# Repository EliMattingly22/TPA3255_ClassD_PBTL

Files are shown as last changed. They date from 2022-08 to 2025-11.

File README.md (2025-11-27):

# TPA3255_ClassD_PBTL
A KiCAD project for the TPA3255 amplifier in PBTL mode

This repository contains schematics, PCB layout and documentation for a compact, rack mountable PBTL (Parallel Bridged) Class‑D amplifier based on the Texas Instruments TPA3255. The design is intended to house three amplifier modules in a single 2U rack enclosure and includes front‑panel controls such as button‑enabled DC‑coupling, balanced XLR inputs/outputs, and protection/status indicators.

## Features

- TPA3255 Class‑D amplifier modules configured in PBTL(parallel bridge-tied load) mode
- Per‑channel button to toggle DC‑coupling
- Balanced XLR inputs
- Per‑channel protection: overcurrent, overtemperature, 
- Clipping indicators
- Per‑channel status LEDs (PWR GOOD / CLIP / FAULT)
- Mechanical layout and enclosure guidance for three amplifiers in a 2U rack unit

## Key electrical parameters

- Supply voltage - 24-52V
  - Power supply current rating should be sufficient for your load. At 50V a 12A supply will be enough for any application, but less is suitable for many other applications. 
- Gain is fixed. G = 21.6(2 Ohms) to 24.4(15 Ohms)
- THD depends on amplitude/power but generally 0.1-0.5%. Better than that in some operating conditions/power levels. 
- Output noise (1-25kHz) is approximately 2 microVolts/sqrt(Hz) 
- Quiescent power draw - about 100 mA per channel
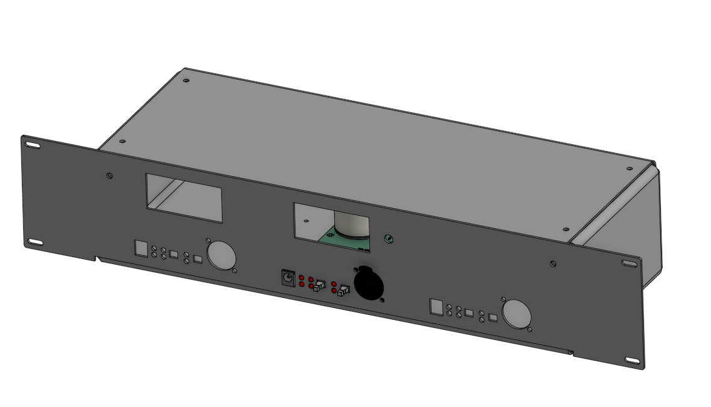
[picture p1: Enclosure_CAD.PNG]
CAD Render

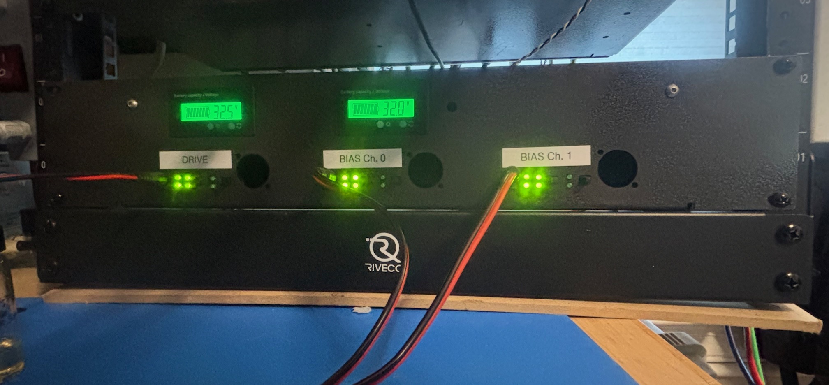
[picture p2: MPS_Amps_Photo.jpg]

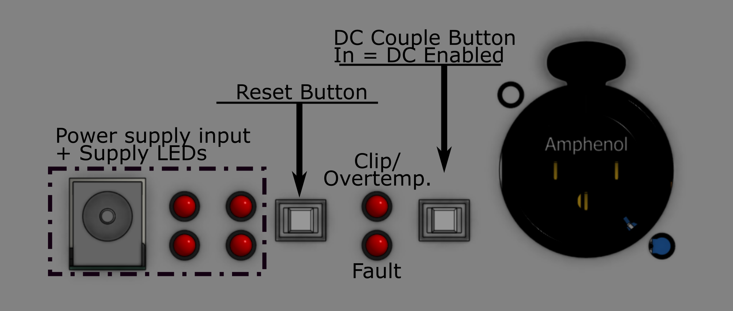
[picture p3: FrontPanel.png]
Indicators/Buttons

## Overview

This project is intended as a general-purpose amplifier capable of replacing the AE Techron 7224 in a variety of lower-power applications. It is a high‑efficiency, medium‑power (300 Watt for sure and up to 600W, in theory...) amplifier solution with balanced I/O and configurable output coupling. The DC‑coupling button lets users switch the amplifier output between AC coupling and DC coupling for use with audio systems or laboratory instruments, etc. that require true DC‑coupled operation. The enclosure is designed to hold three amplifier modules in a 19" 2U rack, with appropriate heatsinking and airflow considerations.

### In this repository:

 - The enclosure is in the top level as: "TPA3255PBTL_Enclosure.step" [Here](TPA3255PBTL_Enclosure.step)
 - There is an add-on board in the directory "Current Control Board" Which allows the user to configure it as a current-mode amplifier with an external current sensor (ACS711)

## Important Design Notes

- Balanced XLR pinout: Pin 1 = GND, Pin 2 = Hot (+), Pin 3 = Cold (−).

- If you enable DC‑coupling, verify output DC offset is within safe limits for connected device. For a transformer, this may be problematic. 

- XLR output: It is not a high-power connector so if the application requires high-current, it would be a good idea to solder directly to the PCB and/or rework the board for a different connector.

## Possible configurations
I designed it for two distinct applications, stepping-DC waveforms (i.e. staircase like waves), and pure sine waves. As the requirements are quite different between the two, there is two output filter configurations. For the DC staircases, the filter uses ferrite cores. For the sine waves, the output filter uses air-core inductors to minimize the risk of adding distortions. 

## Mechanical & Enclosure Guidance (3 amps in 2U rack)

- Standard 19" width, 2U height (88.9 mm). 
- Depth = 145 mm not including XLR connectors, which should have about 100 mm of space for the cable/bend
- XLR inputs on front and rear panel
- Speaker outputs on rear

## BOM notes

- Heatsink hardware = Advanced Thermal Solutions Inc. ATS-TI1OP-519-C1-R3
- Inductor core (for DC version) = Magnetics, a division of Spang & Co., 0079894A7HT19
  - Coated Kool Mu MAX Ferrite Core Toroid Type Length Width 1.060" (26.92mm) Diameter 0.708" (17.99mm) Height
  - Wind with three parallel strands of 18AWG magnet wire, 11 turns 

## Filter inductors

### High power (Lower linearity)
Using ferrite cores improves the efficiency (less copper losses) at the expense of some harmonic distortion. The first-stage core, L2 and L3, must carry the ripple current from the switching. The switching frequency is about 500 kHz (2 uSec period), so if it is switching 50 V every 1 uSec, at periodic steady state when the average voltage across the inductor is 0 V and so each half-period has 25 V across the inductor, the ripple current will be 2.5 A (di/dt = V/L = 25 / 10 uH = 2.5 A/uSec). The original inductor Bourns Inc. 2101-V-RC did not tolerate this well and increased the quiescent current to about 200 mA per channel and induced considerable losses into the system at higher currents. To reduce the inductor losses, this was replaced with the 0079894A7HT19 with 11 turns of three strands of 18AWG magnet wire. This core was chosen for the high saturation magnetization and fairly low losses. The datasheet specifies that the 20% reduction in inductance will occur with 320 Amp-turns so just about 30 Amps, which is more than the amplifier can output anyway. 

### High linearity
Ferrite inductors are inherently nonlinear, so for the applications that require high purity waveforms, an air core inductor was wound and only a single stage of output filtering. The inductor former (rectangular cylinder) is 22mm tall, 35mm OD, 12mm ID, and has 38 turns of 18 AWG magnet wire (about 3.3 m of wire with some extra to be cut off). The inductance was 10 uH and 200 mOhms at 50kHz. Litz wire would reduce the losses somewhat, but I wanted to avoid using Litz for this project. 

## Filter capacitors

The original capacitors (B32529D1105J289) are fine for low-frequency applications, but for >10 kHz, they should be replaced with ones which can tolerate the current being driven into them by the amplifier. At 25 kHz, the reactance is only 6.4 Ohms, so at 50 V there would be nearly 10 A of current flowing into the capacitors. I suggest much larger, much lower loss polypropylene film capacitors (e.g. R76 series or similar, and at least 300VAC rating). They will either need to be bodged onto the board (like I did) or rework the PCB to accomodate it. 

# Measurements

## Output power

### 2.5 Ohm load

After about 3 minutes with a 51V supply, 6 Amps being drawn (306W), the amplifier overheated. It reset via the front-panel button after cooling off.Note: there wasnt much forced air over the fins.

### 5 Ohm load
With 47 Vpk (1 kHz) into 5 Ohm load, the system reached a steady state.
- Heat sink: 67 C
- Small output inductors: 77 C

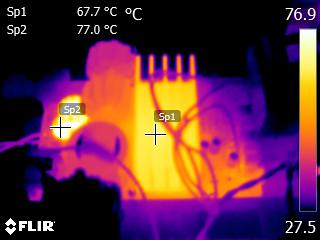
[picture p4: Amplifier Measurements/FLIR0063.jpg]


### 7.7 Ohm load
With 45.8 Vpk (1 kHz) into 7.7 Ohm load, the system reached a steady state.

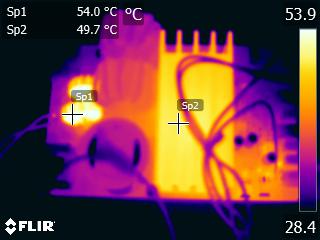
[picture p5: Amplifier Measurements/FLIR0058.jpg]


## Gain

### Air core inductor output filter
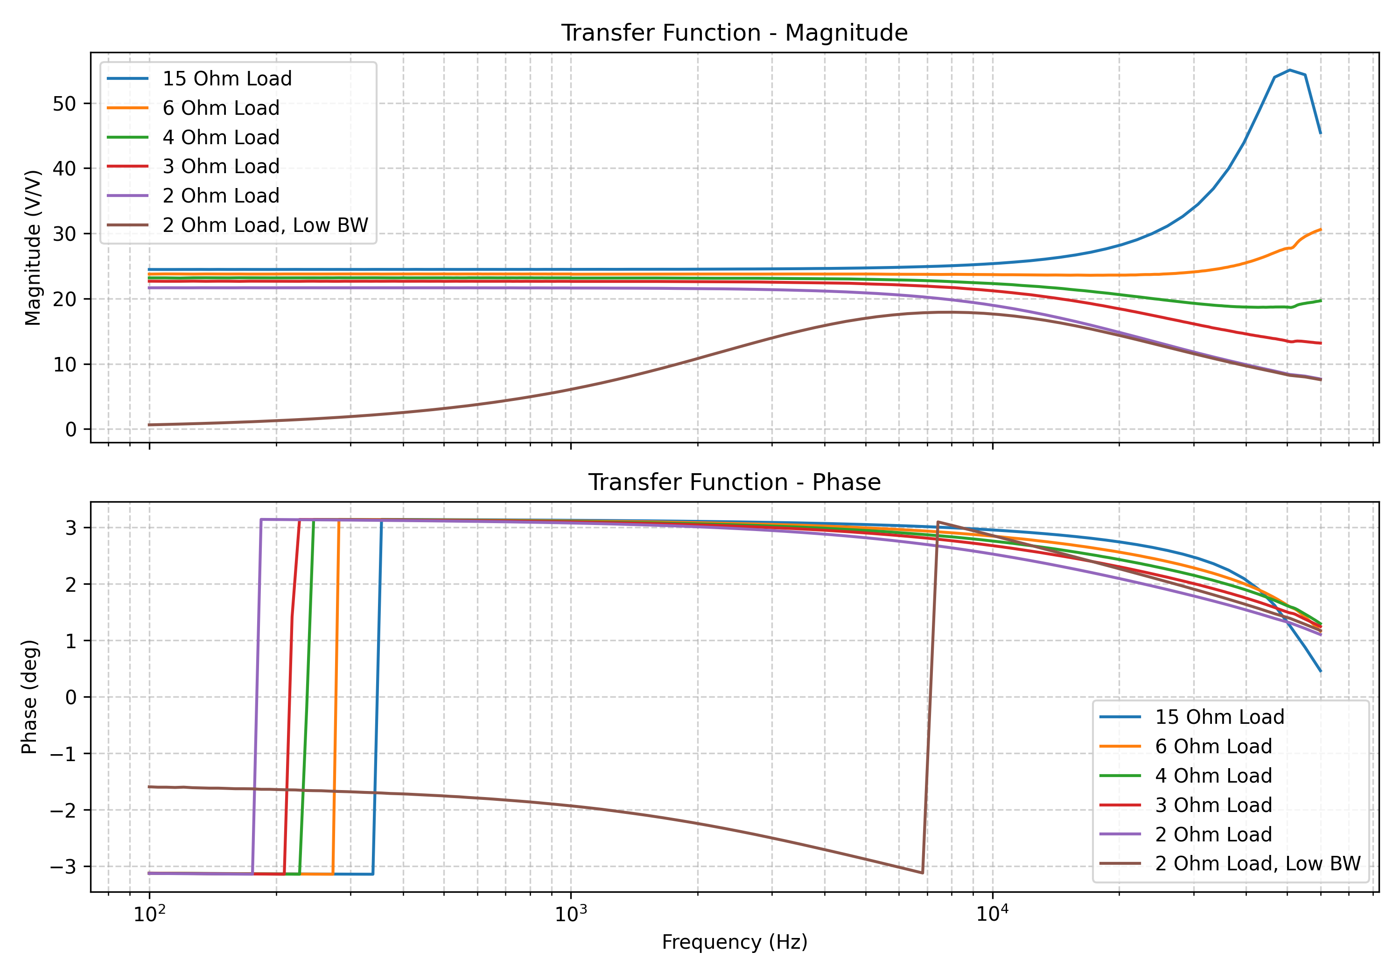
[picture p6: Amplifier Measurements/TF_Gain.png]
Transfer Function - Gain


### Ferrite core inductor output filter
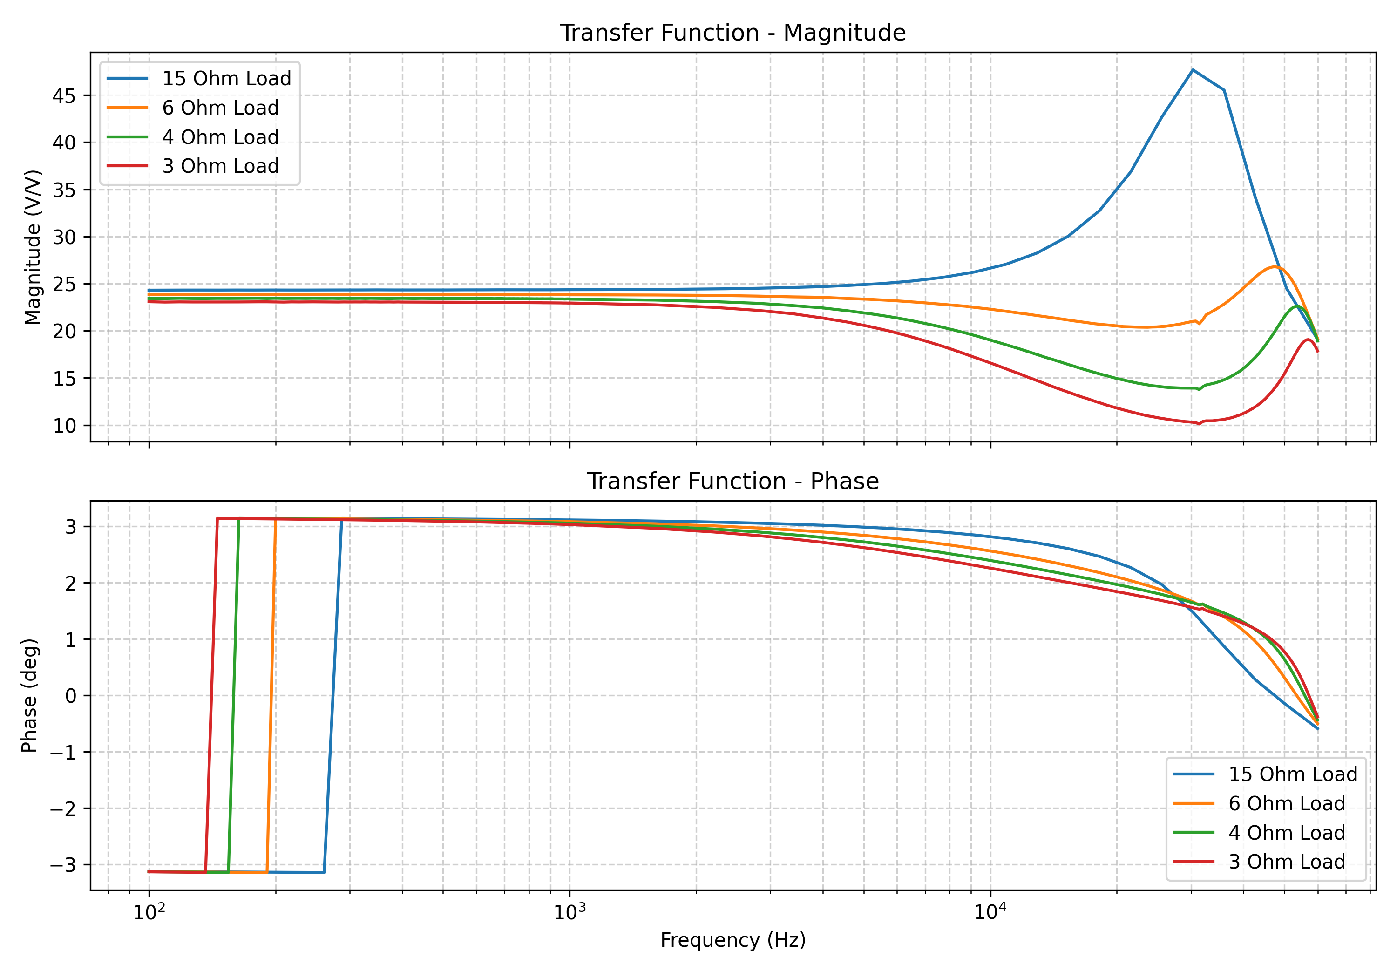
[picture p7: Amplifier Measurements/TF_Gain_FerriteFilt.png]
Transfer Function - Gain


### Low Freq characteristics, effect of jumpers on input
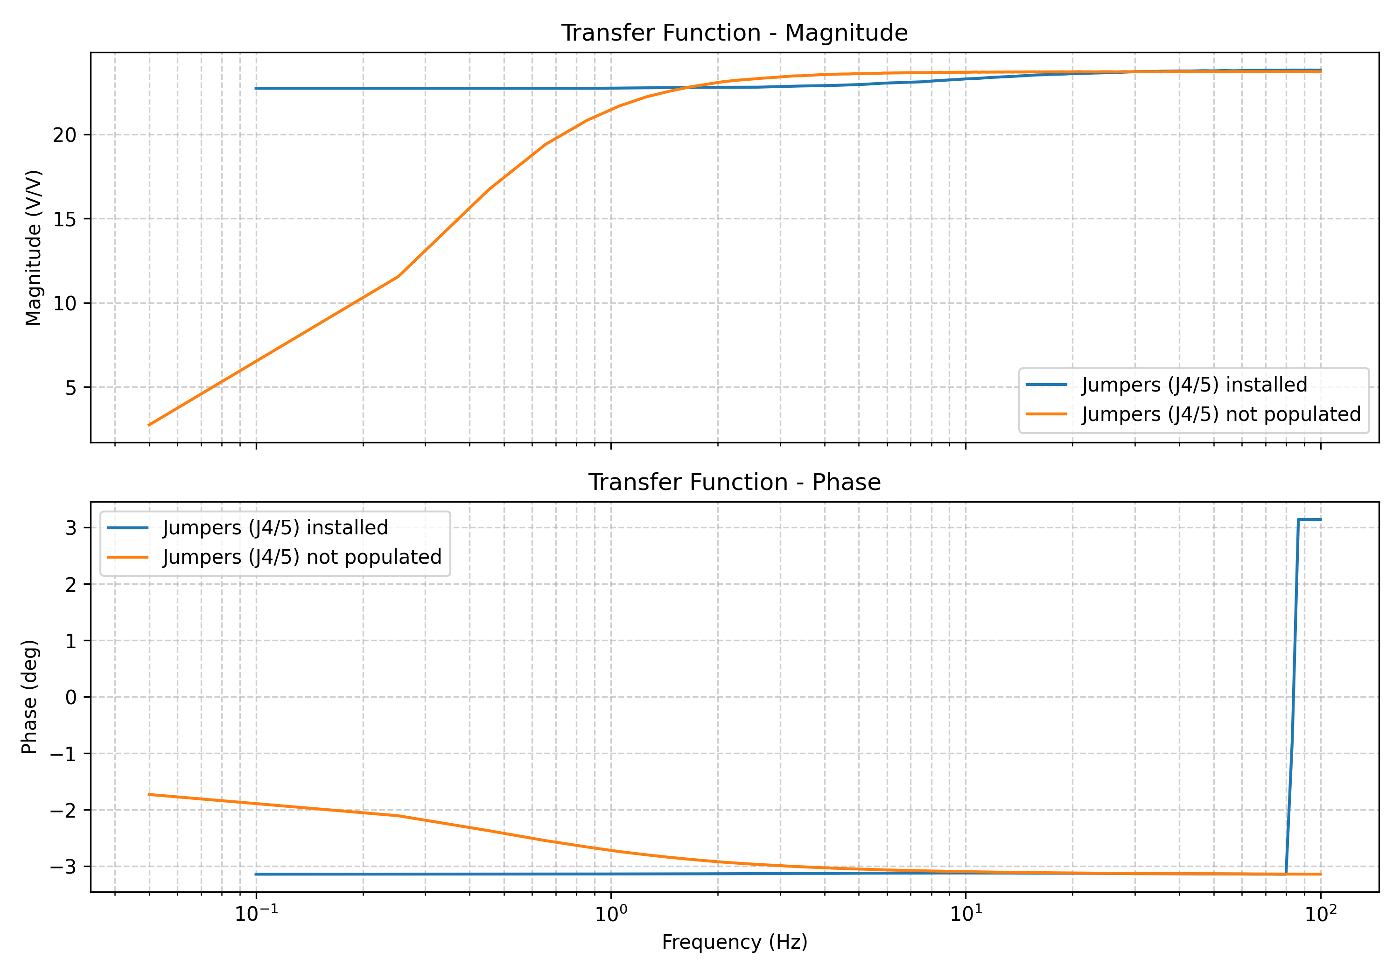
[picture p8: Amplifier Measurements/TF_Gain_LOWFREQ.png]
Transfer Function - Gain


## THD
All measurements with the wide BW/DC enabled mode. Measured the voltage across the load with a RP1025D differential probe 20x range. The probe itself has about 0.1-0.5% THD at 1kHz. 
### Ferrite output filter, 15 Ohm load:

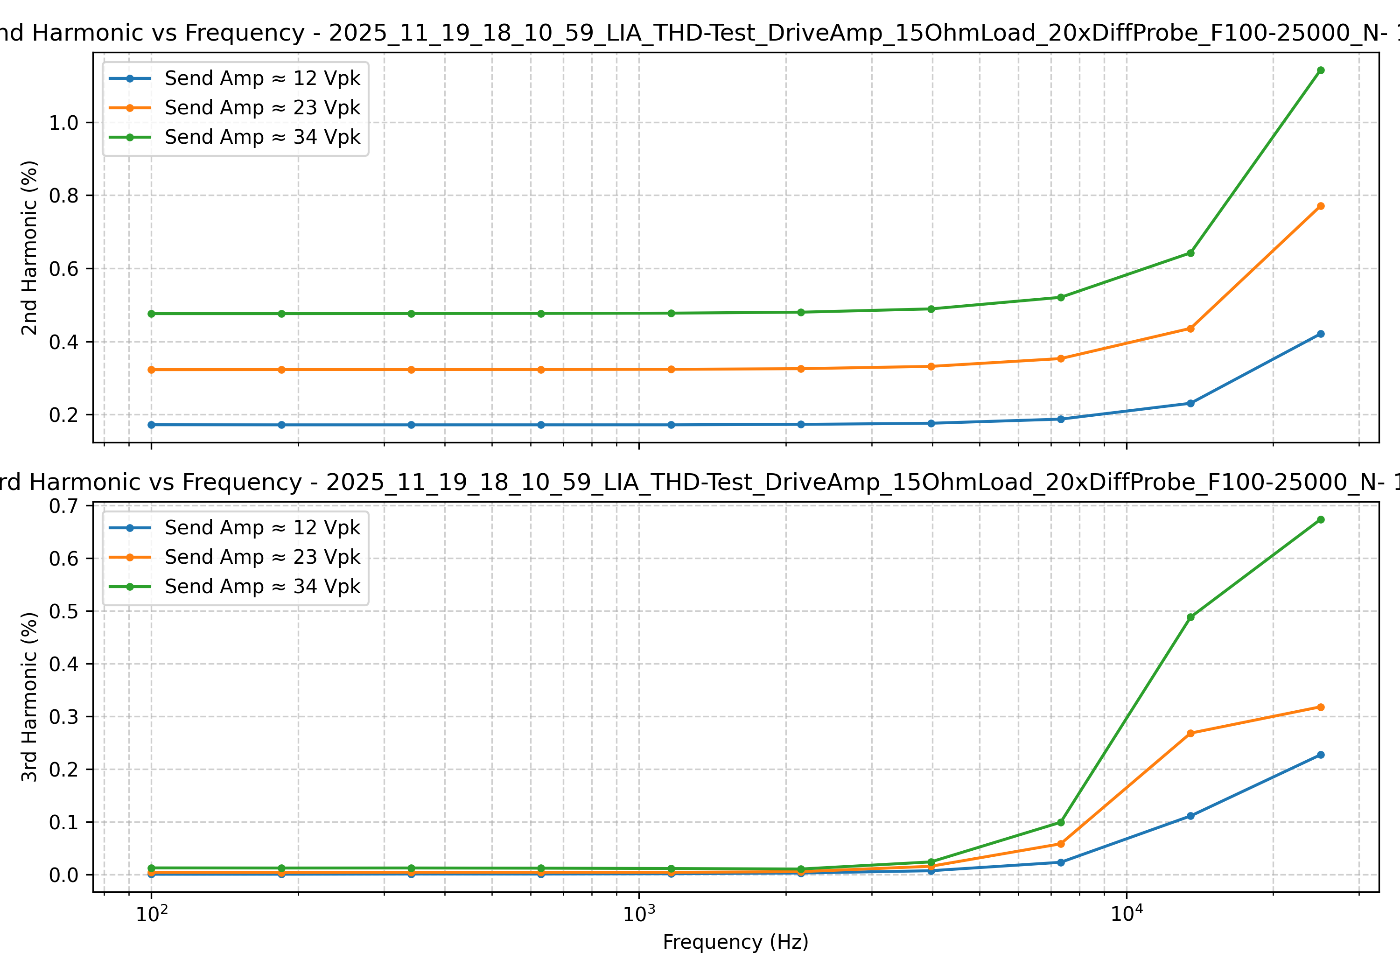
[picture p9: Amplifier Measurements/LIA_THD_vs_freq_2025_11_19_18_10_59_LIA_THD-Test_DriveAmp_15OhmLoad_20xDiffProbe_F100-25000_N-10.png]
THD 16 Ohms


### Air core inductor filter, 15 Ohm load:

THD 16 Ohms

### Air core inductor filter, 2 Ohm load:

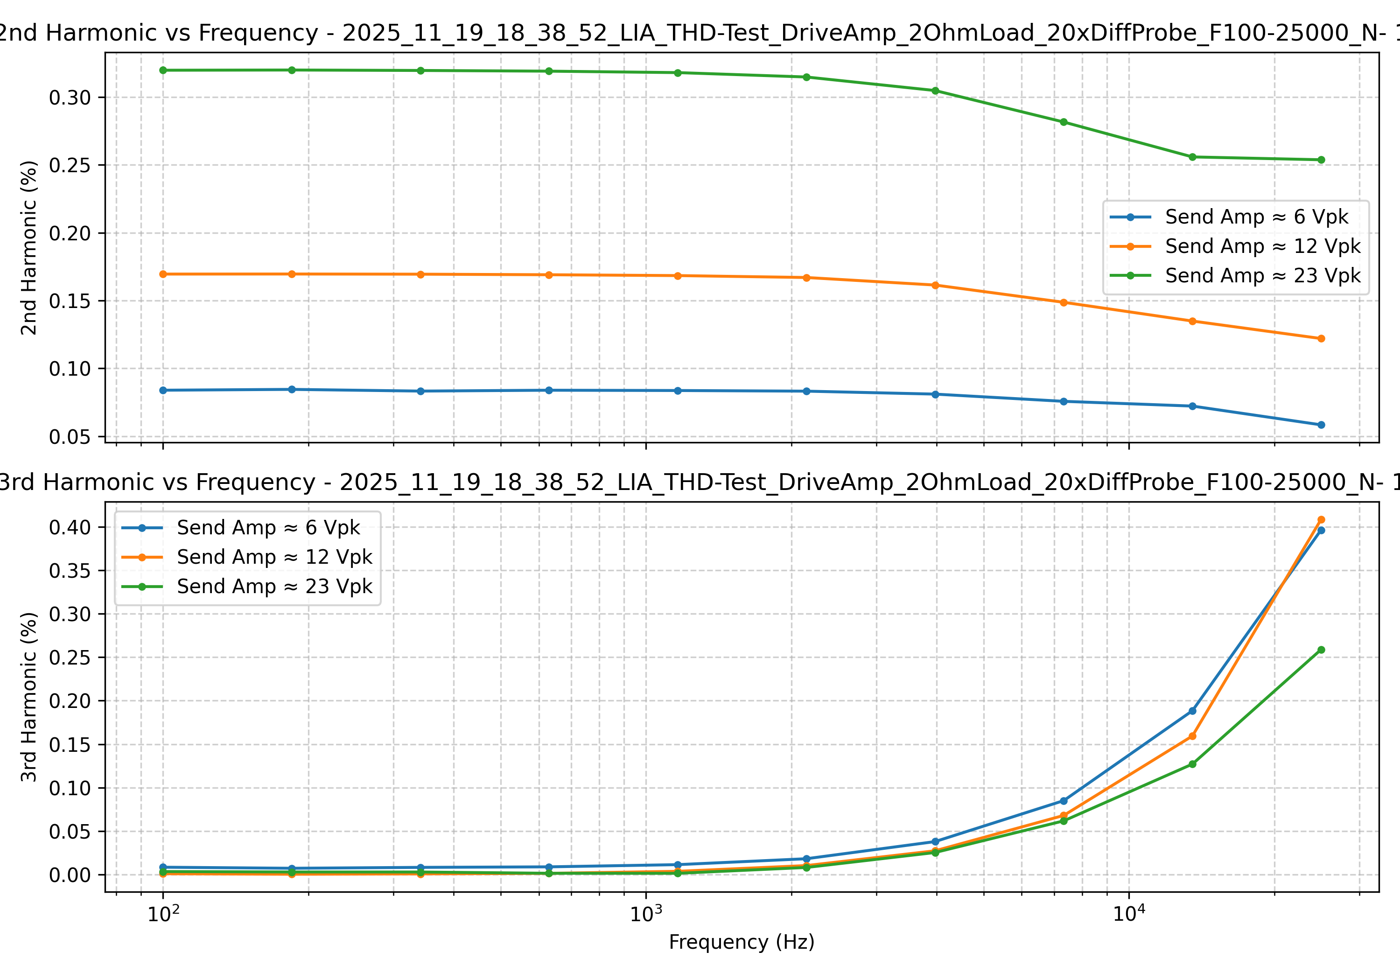
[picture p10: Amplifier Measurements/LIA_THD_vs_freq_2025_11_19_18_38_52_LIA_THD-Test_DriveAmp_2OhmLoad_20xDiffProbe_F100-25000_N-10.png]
THD 2 Ohms


## Noise, input terminated, 2 Ohm load
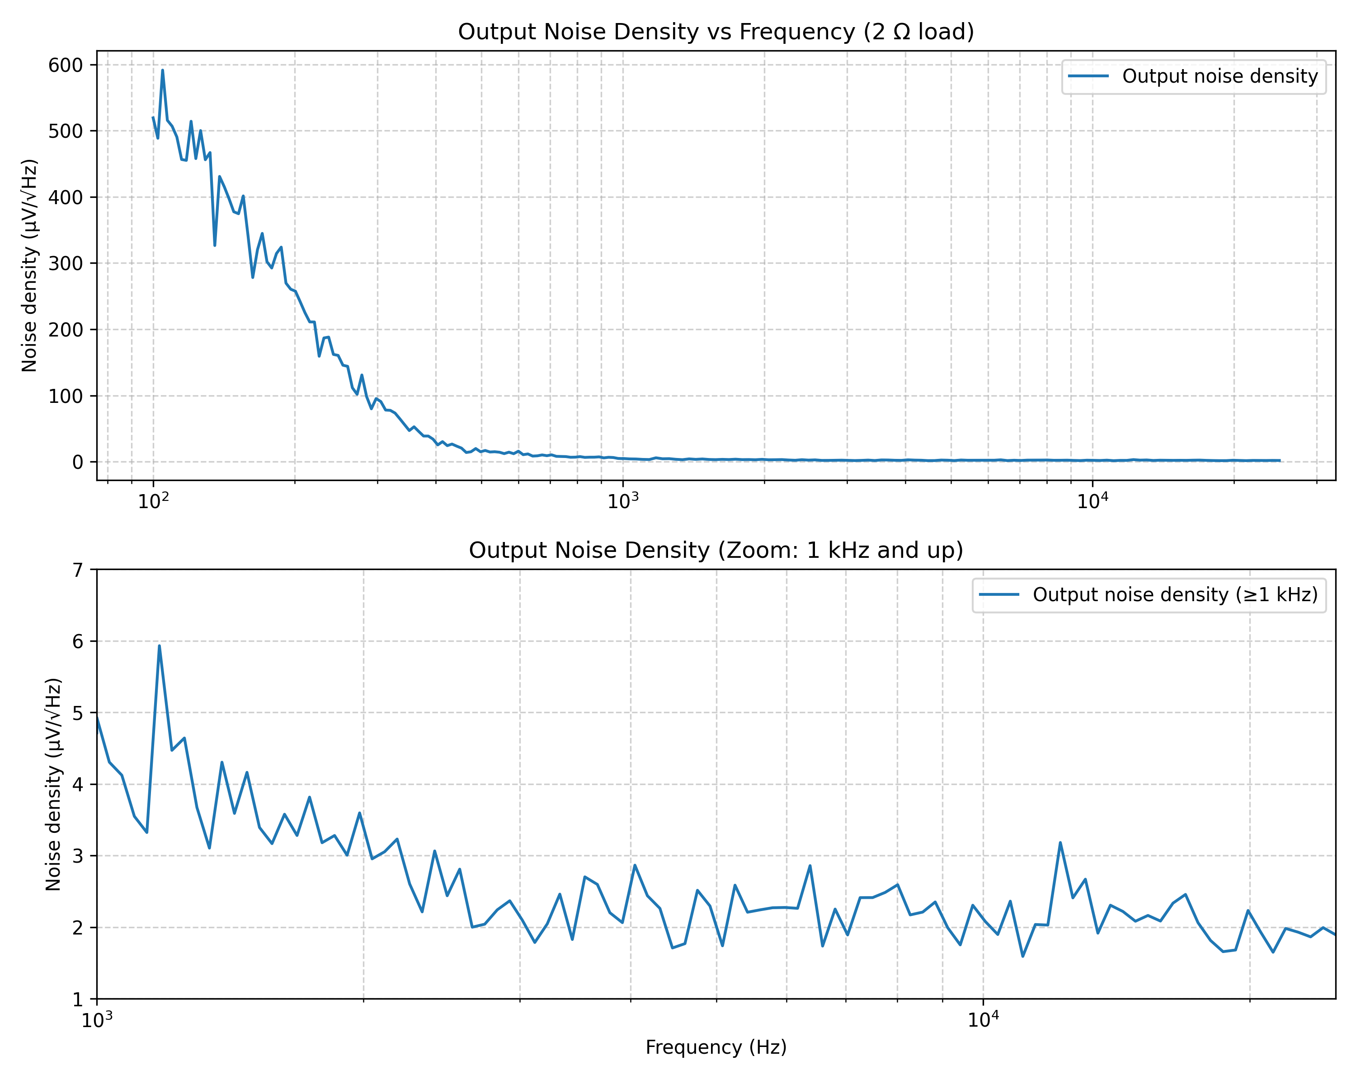
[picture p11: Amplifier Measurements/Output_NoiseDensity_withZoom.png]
Noise spectra


## Safety & Compliance Notes

- DC‑coupled outputs can damage speakers/transformers/other loads if misused 
- For commercial use verify thermal/electrical safety per applicable standards (IEC/UL) and plan for certification where required.

# Schematic details:

The output filter sheet shows the post-switching LC network and probe connectors used to tame the 500 kHz ripple. It is important to keep the filter inductor above 5 uH, per the datasheet. C18/19 present low impedance at high frequencies mitigating some RF noise when the ESL of the larger capacitors would limit their effectiveness. C20/R8 stabilize the impedance at higher frequencies. 

The Second stage filter, L4/C8/C36 and its opposite pair can be included or not depending on the application. They will be a bit lossy but add additional filtering stages to mitigate higher frequency noise. These are not populated in the air core filter version becasuse that application has another filter external to this amplifier board. 

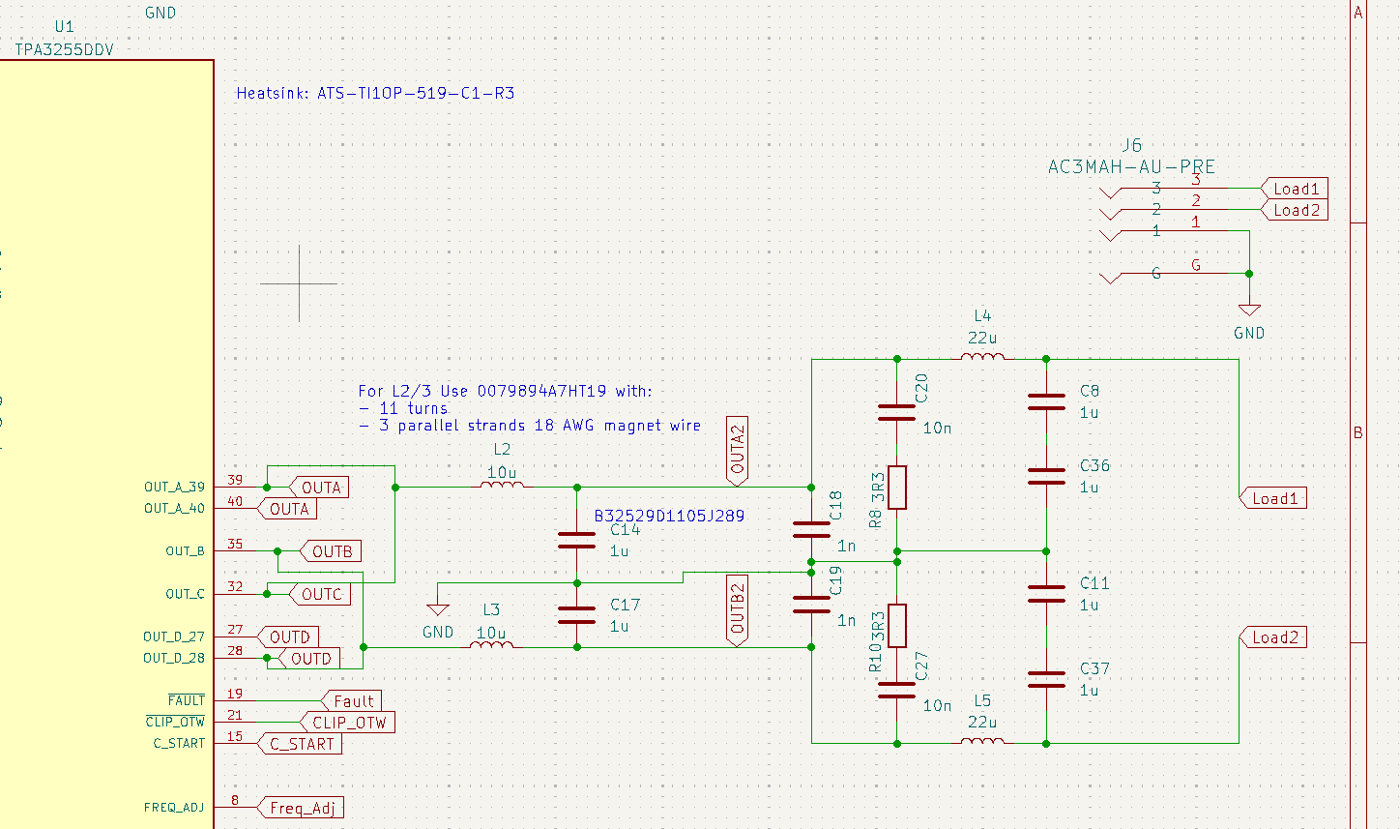
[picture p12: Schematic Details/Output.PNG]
Output Filter


The LED page documents the front-panel status indicators, including the current-limit, clip, and fault drivers tied into the protection logic. See the datasheet for details on the logic. 

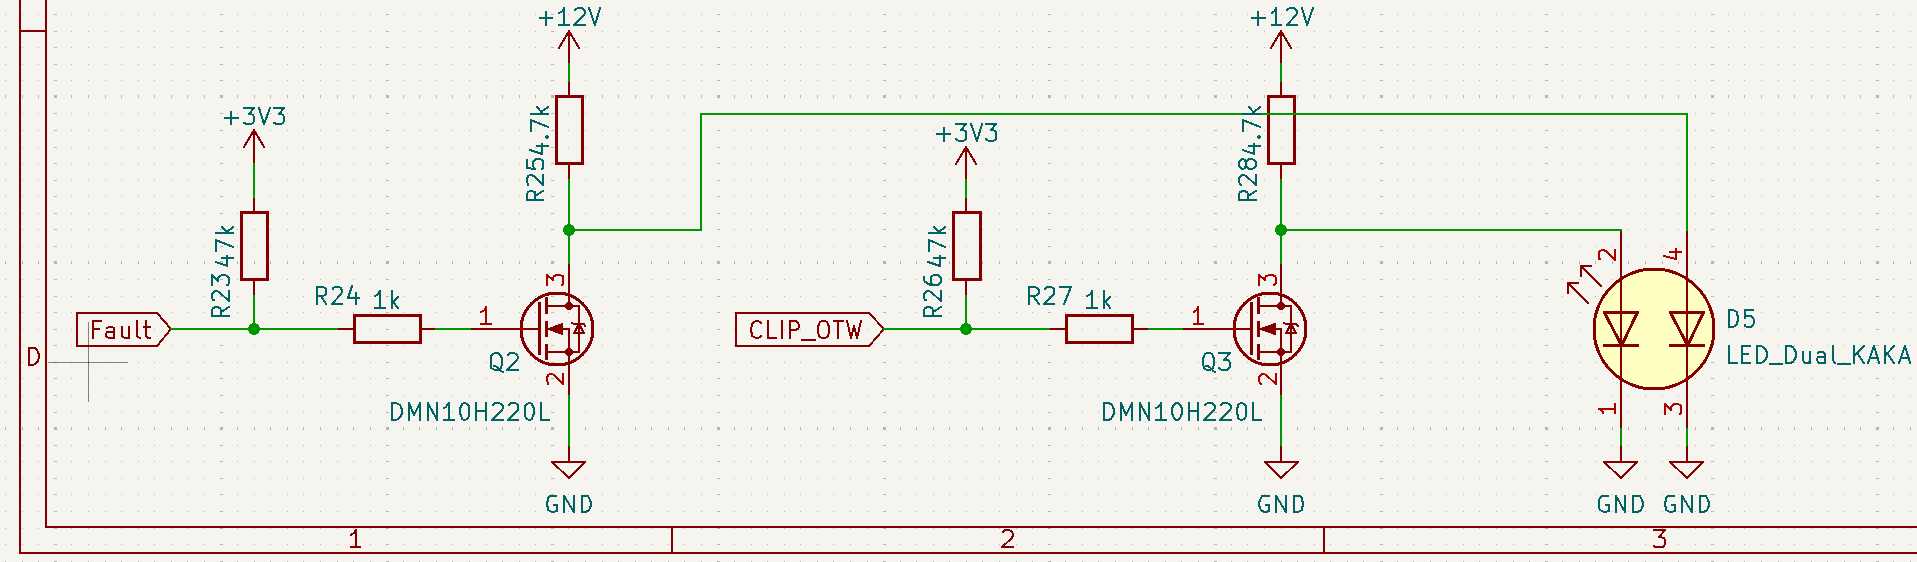
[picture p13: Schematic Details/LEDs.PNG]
LEDs


The power sheet covers the main supply routing, bulk capacitance, and bias regulation stages that feed the TPA3255 module and housekeeping rails.

Note that there is a reverse voltage protection PMOS, the Zener diode protects it from too high VGS.

There are also LEDs to indicate each of the four rails are working (well that there is power to them, they may be enabled but the rails be incorrect). 

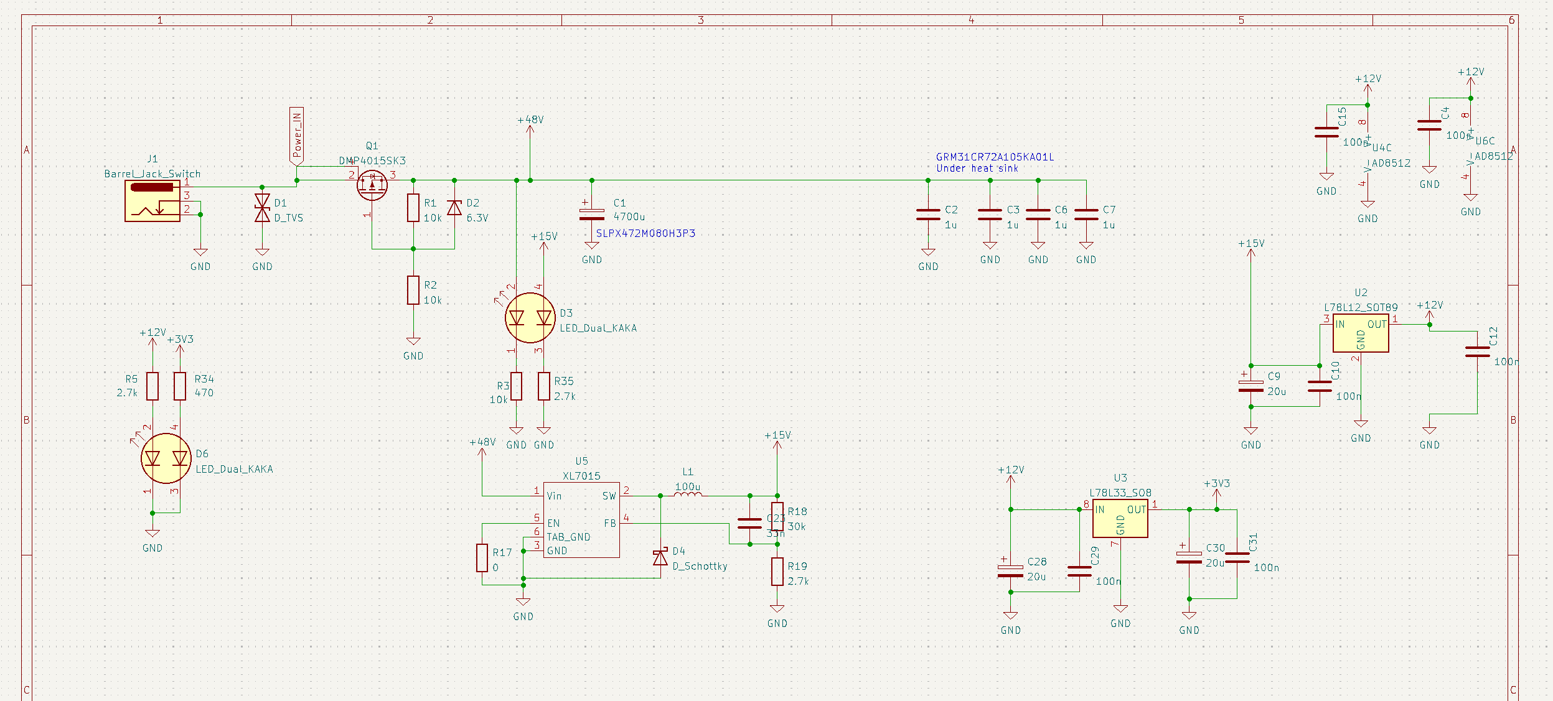
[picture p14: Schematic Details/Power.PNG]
Power


The signals schematic captures the balanced input conditioning, relay-controlled coupling paths, etc.

The signal either passes throught the AC coupling capacitors, C15/43 (the values of which should be chosen based on the application), and are bypassed in DC coupled mode by the latching switch. It then goes through a Diff->SE stage (U4A) which sets the reference point to be 3.8V. The signal then is buffered and turned into a differential signal either going through large AC coupling caps or through jumpers J4/5 which need to be shorted for true DC coupling mode. 

RV1 allows offset trimming.

U7A/B allows for external voltage monitoring, via a home-brew high signal instrumentation amplifier setup, if needed. There is only a test point, but a wire could be easily soldered and a connector added if desired. 

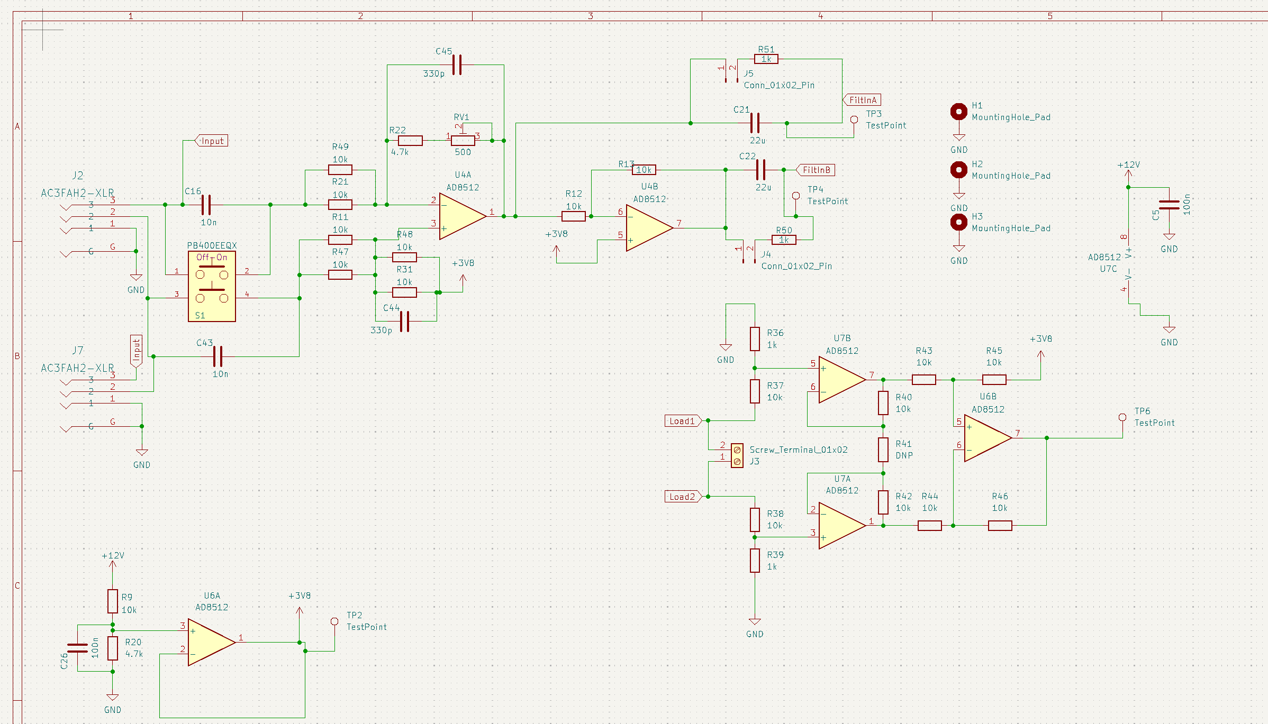
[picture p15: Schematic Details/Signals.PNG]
Signals


The startup page highlights inrush limiting, sequencing, and reset circuitry that ensures the amplifier powers up quietly without tripping protection as suggested by the datasheet. Initially the capacitor holds Q4 low, which means Q5 is enabled, pulling the RST to gnd, but when the capacitor charges, Q4 conducts pulling the gate of Q5 down and R52 pulls RST high.

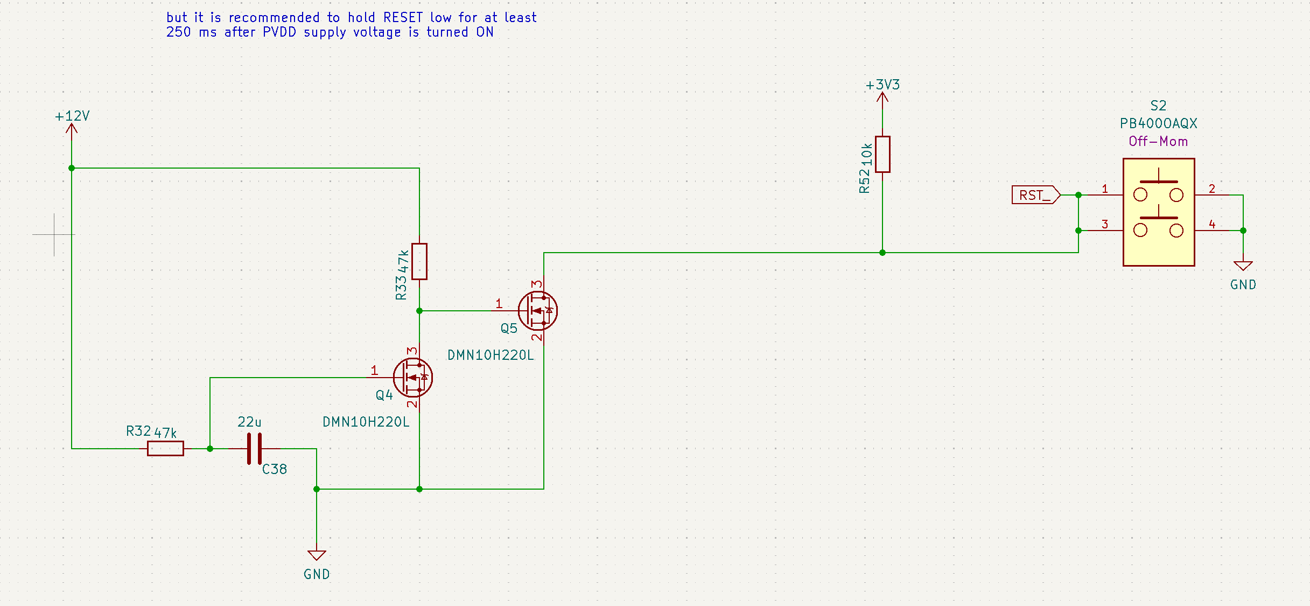
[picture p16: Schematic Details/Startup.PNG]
Startup


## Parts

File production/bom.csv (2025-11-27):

Designator | Footprint | Quantity | Value | LCSC Part #
C1 | CP_Radial_D35.0mm_P10.00mm_SnapIn | 1 | 4700u
C10, C12, C15, C24, C25, C26, C29, C31, C4, C5 | 0805 | 10 | 100n
C11, C14, C17, C36, C37, C8 | C_Rect_L7.2mm_W7.2mm_P5.00mm_FKS2_FKP2_MKS2_MKP2 | 6 | 1u
C13, C40, C41 | 0805 | 3 | 1u
C16, C20, C27, C43 | 0805 | 4 | 10n
C18, C19 | 0805 | 2 | 1n
C2, C3, C6, C7 | 1206 | 4 | 1u
C21, C22, C38 | 1206 | 3 | 47u
C23, C32, C33, C34, C35 | 0805 | 5 | 33n
C28, C30, C9 | CP_Radial_D6.3mm_P2.50mm | 3 | 20u
C42 | 0805 | 1 | 47n
C44, C45 | 0805 | 2 | 330p
D1 | D_SOD-123 | 1 | D_TVS
D2 | D_SOD-123 | 1 | 6.3V
D3, D5, D6 | IC4_WP934EB_2GD_KNB | 3 | LED_Dual_KAKA
D4 | D_SOD-123 | 1 | D_Schottky
J1 | BarrelJack_GCT_DCJ200-10-A_Horizontal | 1 | Barrel_Jack_Switch
J2, J7 | AC3FAH2-F-XLR | 2 | AC3FAH2-XLR
J3 | TerminalBlock_Phoenix_MKDS-1,5-2-5.08_1x02_P5.08mm_Horizontal | 1 | Screw_Terminal_01x02
J4, J5 | PinHeader_1x02_P1.27mm_Vertical | 2 | Conn_01x02_Pin
J6 | AC3MAH-AU-PRE_AMP | 1 | AC3MAH-AU-PRE
L1 | MWPY8040 | 1 | 100u | C501759
L2, L3 | L_Toroid_Vertical_L22.4mm_W10.2mm_P7.90mm_Vishay_TJ4 | 2 | 10u
L4, L5 | L_Toroid_Vertical_L22.4mm_W10.2mm_P7.90mm_Vishay_TJ4 | 2 | 22u
Q1 | TO-252-3_TabPin4 | 1 | DMP4015SK3
Q2, Q3, Q4, Q5 | SOT-23 | 4 | DMN10H220L
R1, R11, R12, R13, R2, R21, R3, R31, R37, R38, R40, R42, R43, R44, R45, R46, R47, R48, R49, R52, R9 | 0805 | 21 | 10k
R10, R8 | 0805 | 2 | 3R3
R14, R15, R16, R17, R4 | 0805 | 5 | 0
R18, R30 | 0805 | 2 | 30k
R19, R35, R5 | 0805 | 3 | 2.7k
R20, R22, R25, R28 | 0805 | 4 | 4.7k
R23, R26, R32, R33 | 0805 | 4 | 47k
R24, R27, R36, R39, R50, R51 | 0805 | 6 | 1k
R29 | 0805 | 1 | 22k
R34 | 0805 | 1 | 470
R6, R7 | 0805 | 2 | 3.3
RV1 | Potentiometer_Bourns_3296W_Vertical | 1 | 500
S1 | SW_PB400EEQX | 1 | PB400EEQX
S2 | SW_PB400EEQX | 1 | PB400OAQX
TP1, TP2, TP3, TP4, TP5, TP6, TP7, TP8 | TestPoint_THTPad_1.0x1.0mm_Drill0.5mm | 8 | TestPoint
U1 | SOP63P810X120-44N | 1 | TPA3255DDV
U2 | SOT-89-3 | 1 | L78L12_SOT89
U3 | SOIC-8_3.9x4.9mm_P1.27mm | 1 | L78L33_SO8
U4, U6, U7 | SO-8_3.9x4.9mm_P1.27mm | 3 | AD8512
U5 | XL7015E1 | 1 | XL7015

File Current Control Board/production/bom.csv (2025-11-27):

Designator | Footprint | Quantity | Value | LCSC Part #
C1 | 0805 | 1 | 47n
C10, C11, C12, C13, C14, C15, C16, C17 | 0805 | 8 | 100n
C2 | 0805 | 1 | 22n
C3 | 0805 | 1 | 10n
C4 | 0805 | 1 | 470p
C5 | 0805 | 1 | 1n
C6, C9 | 0805 | 2 | 10u
C7, C8 | CP_Radial_D6.3mm_P2.50mm | 2 | 100u
D1, D2 | D_SOD-123 | 2 | 2.5
D3, D4 | 0805 | 2 | LED
J1 | AC3FAH2-F-XLR | 1 | AC3FAH2-XLR
J2 | AC3MAH-AU-PRE_AMP | 1 | AC3MAH-AU-PRE
J3, J4, J5 | Banana-FCR7350L | 3 | Banana
J7 | 31-5486-1010 BNC Panel RA | 1 | Conn_Coaxial
R1, R12, R13, R14, R15, R17, R2, R3, R4, R6, R7, R8, R9 | 0805 | 13 | 1k
R10, R11, R18, R19, R20, R5 | 0805 | 6 | 10k
R16 | 0805 | 1 | 220
RV1 | Potentiometer_Bourns_3296W_Vertical | 1 | 10k
SW1 | SW_DIP_SPSTx04_Slide_9.78x12.34mm_W8.61mm_P2.54mm | 1 | SW_DIP_x04
TP1, TP2, TP3, TP4, TP5 | TestPoint_Loop_D2.50mm_Drill1.0mm | 5 | 5002
U1, U2, U3, U4 | SOIC-8_3.9x4.9mm_P1.27mm | 4 | ADA4610-2xR
U5 | SOIC-8_3.9x4.9mm_P1.27mm | 1 | L78L05_SO8

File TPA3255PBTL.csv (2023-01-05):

Source: | C:\Users\elima\OneDrive\Documents\GitHub\TPA3255_ClassD_PBTL\TPA3255PBTL.kicad_sch
Date: | 12/17/2022 9:43:32 PM
Tool: | Eeschema (6.0.0)
Generator: | C:\Program Files\KiCad\6.0\bin\scripting\plugins/bom_csv_grouped_by_value.py
Component Count: | 91
Individual Components:
Item | Qty | Reference(s) | Value | LibPart | Footprint | Datasheet | LCSC | MANUFACTURER | MAXIMUM_PACKAGE_HEIGHT | PARTREV | STANDARD
 |  | C1 | C_Polarized | Device:C_Polarized | Capacitor_THT:CP_Radial_D12.5mm_P5.00mm | ~
 |  | C2 | C_Polarized | Device:C_Polarized | Capacitor_THT:CP_Radial_D12.5mm_P5.00mm | ~
 |  | C3 | C | Device:C | Capacitor_SMD:C_1206_3216Metric | ~
 |  | C4 | C_Polarized | Device:C_Polarized | Capacitor_THT:CP_Radial_D12.5mm_P5.00mm | ~
 |  | C5 | C_Polarized | Device:C_Polarized | Capacitor_THT:CP_Radial_D12.5mm_P5.00mm | ~
 |  | C6 | C | Device:C | Capacitor_SMD:C_1206_3216Metric | ~
 |  | C7 | C | Device:C | Capacitor_SMD:C_1206_3216Metric | ~
 |  | C8 | C | Device:C | Capacitor_SMD:C_1206_3216Metric | ~
 |  | C9 | 20u | Device:C_Polarized | Capacitor_THT:CP_Radial_D5.0mm_P2.50mm | ~
 |  | C10 | 100n | Device:C | Capacitor_SMD:C_0805_2012Metric | ~
 |  | C11 | 20u | Device:C_Polarized | Capacitor_THT:CP_Radial_D5.0mm_P2.50mm | ~
 |  | C12 | 100n | Device:C | Capacitor_SMD:C_0805_2012Metric | ~
 |  | C13 | 1u | Device:C | Capacitor_SMD:C_0805_2012Metric | ~
 |  | C15 | 100n | Device:C | Capacitor_SMD:C_0805_2012Metric | ~
 |  | C16 | 100n | Device:C | Capacitor_SMD:C_0805_2012Metric | ~
 |  | C17 | 10n | Device:C | Capacitor_SMD:C_0805_2012Metric | ~
 |  | C18 | 1n | Device:C | Capacitor_SMD:C_0805_2012Metric | ~
 |  | C19 | 100p | Device:C | Capacitor_SMD:C_0805_2012Metric | ~
 |  | C20 | 100n | Device:C | Capacitor_SMD:C_0805_2012Metric | ~
 |  | C21 | 1u | Device:C | Capacitor_SMD:C_0805_2012Metric | ~
 |  | C22 | 1u | Device:C | Capacitor_SMD:C_0805_2012Metric | ~
 |  | C23 | 33n | Device:C | Capacitor_SMD:C_0805_2012Metric | ~
 |  | C24 | 100n | Device:C | Capacitor_SMD:C_0805_2012Metric | ~
 |  | C25 | 100n | Device:C | Capacitor_SMD:C_0805_2012Metric | ~
 |  | C26 | 100n | Device:C | Capacitor_SMD:C_0805_2012Metric | ~
 |  | C27 | 100n | Device:C | Capacitor_SMD:C_0805_2012Metric | ~
 |  | C28 | 20u | Device:C_Polarized | Capacitor_THT:CP_Radial_D5.0mm_P2.50mm | ~
 |  | C29 | 100n | Device:C | Capacitor_SMD:C_0805_2012Metric | ~
 |  | C30 | 20u | Device:C_Polarized | Capacitor_THT:CP_Radial_D5.0mm_P2.50mm | ~
 |  | C31 | 100n | Device:C | Capacitor_SMD:C_0805_2012Metric | ~
 |  | C32 | 33n | Device:C | Capacitor_SMD:C_0805_2012Metric | ~
 |  | C33 | 33n | Device:C | Capacitor_SMD:C_0805_2012Metric | ~
 |  | C34 | 33n | Device:C | Capacitor_SMD:C_0805_2012Metric | ~
 |  | C35 | 33n | Device:C | Capacitor_SMD:C_0805_2012Metric | ~
 |  | C38 | 4.7n | Device:C | Capacitor_THT:C_Rect_L18.0mm_W6.0mm_P15.00mm_FKS3_FKP3 | ~
 |  | C39 | 4.7n | Device:C | Capacitor_THT:C_Rect_L18.0mm_W6.0mm_P15.00mm_FKS3_FKP3 | ~
 |  | C40 | 1u | Device:C | Capacitor_SMD:C_0805_2012Metric | ~
 |  | C41 | 1u | Device:C | Capacitor_SMD:C_0805_2012Metric | ~
 |  | C42 | 100n | Device:C | Capacitor_SMD:C_0805_2012Metric | ~
 |  | D1 | D_TVS | Device:D_TVS | Diode_SMD:D_SOD-123 | ~
 |  | D2 | 6.3V | Device:D_Zener | Diode_SMD:D_SOD-123 | ~
 |  | D3 | LED | Device:LED | LED_THT:LED_D3.0mm_Horizontal_O1.27mm_Z2.0mm | ~
 |  | D4 | D_Schottky | Device:D_Schottky | Diode_SMD:D_SOD-123 | ~
 |  | D5 | LED | Device:LED | LED_THT:LED_D3.0mm_Horizontal_O1.27mm_Z2.0mm | ~
 |  | D6 | LED | Device:LED | LED_THT:LED_D3.0mm_Horizontal_O1.27mm_Z2.0mm | ~
 |  | D7 | LED | Device:LED | LED_THT:LED_D3.0mm_Horizontal_O1.27mm_Z2.0mm | ~
 |  | J1 | Barrel_Jack_Switch | Connector:Barrel_Jack_Switch | Connector_BarrelJack:BarrelJack_GCT_DCJ200-10-A_Horizontal | ~
 |  | J2 | Conn_Coaxial | Connector:Conn_Coaxial | Connector_Coaxial:BNC_TEConnectivity_1478035_Horizontal | ~
 |  | J3 | Conn_02x04_Odd_Even | Connector_Generic:Conn_02x04_Odd_Even | Connector_PinHeader_2.54mm:PinHeader_2x04_P2.54mm_Vertical | ~
 |  | L1 | 100u | Device:L | Eli_Lib:MWPY8040 | ~ | C501759
 |  | L2 | 10u | Device:L | Inductor_THT:L_Toroid_Vertical_L22.4mm_W10.2mm_P7.90mm_Vishay_TJ4 | ~
 |  | L3 | 10u | Device:L | Inductor_THT:L_Toroid_Vertical_L22.4mm_W10.2mm_P7.90mm_Vishay_TJ4 | ~
 |  | Q1 | DMP4015SK3 | Eli:DMP4015SK3 | Package_TO_SOT_SMD:TO-252-3_TabPin4 | ~
 |  | Q2 | DMN10H220L | Transistor_FET:DMN10H220L | Package_TO_SOT_SMD:SOT-23 | http://www.diodes.com/assets/Datasheets/DMN10H220L.pdf
 |  | Q3 | DMN10H220L | Transistor_FET:DMN10H220L | Package_TO_SOT_SMD:SOT-23 | http://www.diodes.com/assets/Datasheets/DMN10H220L.pdf
 |  | R1 | 10k | Device:R | Resistor_SMD:R_0805_2012Metric | ~
 |  | R2 | 10k | Device:R | Resistor_SMD:R_0805_2012Metric | ~
 |  | R3 | 10k | Device:R | Resistor_SMD:R_0805_2012Metric | ~
 |  | R4 | 0 | Device:R | Resistor_SMD:R_0805_2012Metric | ~
 |  | R5 | 1k | Device:R | Resistor_SMD:R_0805_2012Metric | ~
 |  | R6 | 3.3 | Device:R | Resistor_SMD:R_0805_2012Metric | ~
 |  | R7 | 3.3 | Device:R | Resistor_SMD:R_0805_2012Metric | ~
 |  | R8 | 10k | Device:R | Resistor_SMD:R_0805_2012Metric | ~
 |  | R9 | 10k | Device:R | Resistor_SMD:R_0805_2012Metric | ~
 |  | R10 | 10k | Device:R | Resistor_SMD:R_0805_2012Metric | ~
 |  | R11 | 10k | Device:R | Resistor_SMD:R_0805_2012Metric | ~
 |  | R12 | 10k | Device:R | Resistor_SMD:R_0805_2012Metric | ~
 |  | R13 | 10k | Device:R | Resistor_SMD:R_0805_2012Metric | ~
 |  | R14 | 0 | Device:R | Resistor_SMD:R_0805_2012Metric | ~
 |  | R15 | 0 | Device:R | Resistor_SMD:R_0805_2012Metric | ~
 |  | R16 | 0 | Device:R | Resistor_SMD:R_0805_2012Metric | ~
 |  | R17 | 0 | Device:R | Resistor_SMD:R_0805_2012Metric | ~
 |  | R18 | 30k | Device:R | Resistor_SMD:R_0805_2012Metric | ~
 |  | R19 | 2.7k | Device:R | Resistor_SMD:R_0805_2012Metric | ~
 |  | R20 | 10k | Device:R | Resistor_SMD:R_0805_2012Metric | ~
 |  | R21 | 10k | Device:R | Resistor_SMD:R_0805_2012Metric | ~
 |  | R22 | 10k | Device:R | Resistor_SMD:R_0805_2012Metric | ~
 |  | R23 | 47k | Device:R | Resistor_SMD:R_0805_2012Metric | ~
 |  | R24 | 1k | Device:R | Resistor_SMD:R_0805_2012Metric | ~
 |  | R25 | 4.7k | Device:R | Resistor_SMD:R_0805_2012Metric | ~
 |  | R26 | 47k | Device:R | Resistor_SMD:R_0805_2012Metric | ~
 |  | R27 | 1k | Device:R | Resistor_SMD:R_0805_2012Metric | ~
 |  | R28 | 4.7k | Device:R | Resistor_SMD:R_0805_2012Metric | ~
 |  | R29 | 22k | Device:R | Resistor_SMD:R_0805_2012Metric | ~
 |  | R30 | 30k | Device:R | Resistor_SMD:R_0805_2012Metric | ~
 |  | SW1 | SW_Push_Dual | Switch:SW_Push_Dual | Button_Switch_SMD:SW_SPST_Omron_B3FS-105xP | ~
 |  | U1 | TPA3255DDV | Eli_v6Lib:TPA3255DDV | Eli_Lib:SOP63P810X120-44N |  |  | Texas Instruments | 1.2 mm | A | IPC-7351B
 |  | U2 | L78L12_SOT89 | Regulator_Linear:L78L12_SOT89 | Package_TO_SOT_SMD:SOT-89-3 | http://www.st.com/content/ccc/resource/technical/document/datasheet/15/55/e5/aa/23/5b/43/fd/CD00000446.pdf/files/CD00000446.pdf/jcr:content/translations/en.CD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
 |  | U3 | L78L33_SO8 | Regulator_Linear:L78L33_SO8 | Package_SO:SOIC-8_3.9x4.9mm_P1.27mm | http://www.st.com/content/ccc/resource/technical/document/datasheet/15/55/e5/aa/23/5b/43/fd/CD00000446.pdf/files/CD00000446.pdf/jcr:content/translations/en.CD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
 |  | U4 | NE5532 | Amplifier_Operational:NE5532 | Package_SO:SO-8_3.9x4.9mm_P1.27mm | http://www.ti.com/lit/ds/symlink/ne5532.pdf
 |  | U5 | XL7015 | Eli_v6Lib:XL7015 | Package_TO_SOT_SMD:TO-252-5_TabPin6
Collated Components:
Item | Qty | Reference(s) | Value | LibPart | Footprint | Datasheet | LCSC | MANUFACTURER | MAXIMUM_PACKAGE_HEIGHT | PARTREV | STANDARD
1 | 4 | C1, C2, C4, C5 | C_Polarized | Device:C_Polarized | Capacitor_THT:CP_Radial_D12.5mm_P5.00mm | ~
2 | 4 | C3, C6, C7, C8 | C | Device:C | Capacitor_SMD:C_1206_3216Metric | ~
3 | 4 | C9, C11, C28, C30 | 20u | Device:C_Polarized | Capacitor_THT:CP_Radial_D5.0mm_P2.50mm | ~
4 | 12 | C10, C12, C15, C16, C20, C24, C25, C26, C27, C29, C31, C42 | 100n | Device:C | Capacitor_SMD:C_0805_2012Metric | ~
5 | 5 | C13, C21, C22, C40, C41 | 1u | Device:C | Capacitor_SMD:C_0805_2012Metric | ~
6 | 1 | C17 | 10n | Device:C | Capacitor_SMD:C_0805_2012Metric | ~
7 | 1 | C18 | 1n | Device:C | Capacitor_SMD:C_0805_2012Metric | ~
8 | 1 | C19 | 100p | Device:C | Capacitor_SMD:C_0805_2012Metric | ~
9 | 5 | C23, C32, C33, C34, C35 | 33n | Device:C | Capacitor_SMD:C_0805_2012Metric | ~
10 | 2 | C38, C39 | 4.7n | Device:C | Capacitor_THT:C_Rect_L18.0mm_W6.0mm_P15.00mm_FKS3_FKP3 | ~
11 | 1 | D1 | D_TVS | Device:D_TVS | Diode_SMD:D_SOD-123 | ~
12 | 1 | D2 | 6.3V | Device:D_Zener | Diode_SMD:D_SOD-123 | ~
13 | 4 | D3, D5, D6, D7 | LED | Device:LED | LED_THT:LED_D3.0mm_Horizontal_O1.27mm_Z2.0mm | ~
14 | 1 | D4 | D_Schottky | Device:D_Schottky | Diode_SMD:D_SOD-123 | ~
15 | 1 | J1 | Barrel_Jack_Switch | Connector:Barrel_Jack_Switch | Connector_BarrelJack:BarrelJack_GCT_DCJ200-10-A_Horizontal | ~
16 | 1 | J2 | Conn_Coaxial | Connector:Conn_Coaxial | Connector_Coaxial:BNC_TEConnectivity_1478035_Horizontal | ~
17 | 1 | J3 | Conn_02x04_Odd_Even | Connector_Generic:Conn_02x04_Odd_Even | Connector_PinHeader_2.54mm:PinHeader_2x04_P2.54mm_Vertical | ~
18 | 1 | L1 | 100u | Device:L | Eli_Lib:MWPY8040 | ~ | C501759
19 | 2 | L2, L3 | 10u | Device:L | Inductor_THT:L_Toroid_Vertical_L22.4mm_W10.2mm_P7.90mm_Vishay_TJ4 | ~
20 | 1 | Q1 | DMP4015SK3 | Eli:DMP4015SK3 | Package_TO_SOT_SMD:TO-252-3_TabPin4 | ~
21 | 2 | Q2, Q3 | DMN10H220L | Transistor_FET:DMN10H220L | Package_TO_SOT_SMD:SOT-23 | http://www.diodes.com/assets/Datasheets/DMN10H220L.pdf
22 | 12 | R1, R2, R3, R8, R9, R10, R11, R12, R13, R20, R21, R22 | 10k | Device:R | Resistor_SMD:R_0805_2012Metric | ~
23 | 5 | R4, R14, R15, R16, R17 | 0 | Device:R | Resistor_SMD:R_0805_2012Metric | ~
24 | 3 | R5, R24, R27 | 1k | Device:R | Resistor_SMD:R_0805_2012Metric | ~
25 | 2 | R6, R7 | 3.3 | Device:R | Resistor_SMD:R_0805_2012Metric | ~
26 | 2 | R18, R30 | 30k | Device:R | Resistor_SMD:R_0805_2012Metric | ~
27 | 1 | R19 | 2.7k | Device:R | Resistor_SMD:R_0805_2012Metric | ~
28 | 2 | R23, R26 | 47k | Device:R | Resistor_SMD:R_0805_2012Metric | ~
29 | 2 | R25, R28 | 4.7k | Device:R | Resistor_SMD:R_0805_2012Metric | ~
30 | 1 | R29 | 22k | Device:R | Resistor_SMD:R_0805_2012Metric | ~
31 | 1 | SW1 | SW_Push_Dual | Switch:SW_Push_Dual | Button_Switch_SMD:SW_SPST_Omron_B3FS-105xP | ~
32 | 1 | U1 | TPA3255DDV | Eli_v6Lib:TPA3255DDV | Eli_Lib:SOP63P810X120-44N |  |  | Texas Instruments | 1.2 mm | A | IPC-7351B
33 | 1 | U2 | L78L12_SOT89 | Regulator_Linear:L78L12_SOT89 | Package_TO_SOT_SMD:SOT-89-3 | http://www.st.com/content/ccc/resource/technical/document/datasheet/15/55/e5/aa/23/5b/43/fd/CD00000446.pdf/files/CD00000446.pdf/jcr:content/translations/en.CD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
34 | 1 | U3 | L78L33_SO8 | Regulator_Linear:L78L33_SO8 | Package_SO:SOIC-8_3.9x4.9mm_P1.27mm | http://www.st.com/content/ccc/resource/technical/document/datasheet/15/55/e5/aa/23/5b/43/fd/CD00000446.pdf/files/CD00000446.pdf/jcr:content/translations/en.CD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
35 | 1 | U4 | NE5532 | Amplifier_Operational:NE5532 | Package_SO:SO-8_3.9x4.9mm_P1.27mm | http://www.ti.com/lit/ds/symlink/ne5532.pdf
36 | 1 | U5 | XL7015 | Eli_v6Lib:XL7015 | Package_TO_SOT_SMD:TO-252-5_TabPin6

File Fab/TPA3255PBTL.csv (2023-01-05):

Comment | Designator | Footprint
C_Polarized | C1, C2, C4, C5 | Capacitor_THT:CP_Radial_D12.5mm_P5.00mm
C | C3, C6, C7, C8 | Capacitor_SMD:C_1206_3216Metric
20u | C9, C11, C28, C30 | Capacitor_THT:CP_Radial_D5.0mm_P2.50mm
100n | C10, C12, C15, C16, C20, C24, C25, C26, C27, C29, C31, C42 | Capacitor_SMD:C_0805_2012Metric
1u | C13, C21, C22, C40, C41 | Capacitor_SMD:C_0805_2012Metric
10n | C17 | Capacitor_SMD:C_0805_2012Metric
1n | C18 | Capacitor_SMD:C_0805_2012Metric
100p | C19 | Capacitor_SMD:C_0805_2012Metric
33n | C23, C32, C33, C34, C35 | Capacitor_SMD:C_0805_2012Metric
4.7n | C38, C39 | Capacitor_THT:C_Rect_L18.0mm_W6.0mm_P15.00mm_FKS3_FKP3
D_TVS | D1 | Diode_SMD:D_SOD-123
6.3V | D2 | Diode_SMD:D_SOD-123
LED | D3, D5, D6, D7 | LED_THT:LED_D3.0mm_Horizontal_O1.27mm_Z2.0mm
D_Schottky | D4 | Diode_SMD:D_SOD-123
Barrel_Jack_Switch | J1 | Connector_BarrelJack:BarrelJack_GCT_DCJ200-10-A_Horizontal
Conn_Coaxial | J2 | Connector_Coaxial:BNC_TEConnectivity_1478035_Horizontal
Conn_02x04_Odd_Even | J3 | Connector_PinHeader_2.54mm:PinHeader_2x04_P2.54mm_Vertical
100u | L1 | Eli_Lib:MWPY8040
10u | L2, L3 | Inductor_THT:L_Toroid_Vertical_L22.4mm_W10.2mm_P7.90mm_Vishay_TJ4
DMP4015SK3 | Q1 | Package_TO_SOT_SMD:TO-252-3_TabPin4
DMN10H220L | Q2, Q3 | Package_TO_SOT_SMD:SOT-23
10k | R1, R2, R3, R8, R9, R10, R11, R12, R13, R20, R21, R22 | Resistor_SMD:R_0805_2012Metric
0 | R4, R14, R15, R16, R17 | Resistor_SMD:R_0805_2012Metric
1k | R5, R24, R27 | Resistor_SMD:R_0805_2012Metric
3.3 | R6, R7 | Resistor_SMD:R_0805_2012Metric
30k | R18, R30 | Resistor_SMD:R_0805_2012Metric
2.7k | R19 | Resistor_SMD:R_0805_2012Metric
47k | R23, R26 | Resistor_SMD:R_0805_2012Metric
4.7k | R25, R28 | Resistor_SMD:R_0805_2012Metric
22k | R29 | Resistor_SMD:R_0805_2012Metric
SW_Push_Dual | SW1 | Button_Switch_SMD:SW_SPST_Omron_B3FS-105xP
TPA3255DDV | U1 | Eli_Lib:SOP63P810X120-44N
L78L12_SOT89 | U2 | Package_TO_SOT_SMD:SOT-89-3
L78L33_SO8 | U3 | Package_SO:SOIC-8_3.9x4.9mm_P1.27mm
NE5532 | U4 | Package_SO:SO-8_3.9x4.9mm_P1.27mm
XL7015 | U5 | Package_TO_SOT_SMD:TO-252-5_TabPin6

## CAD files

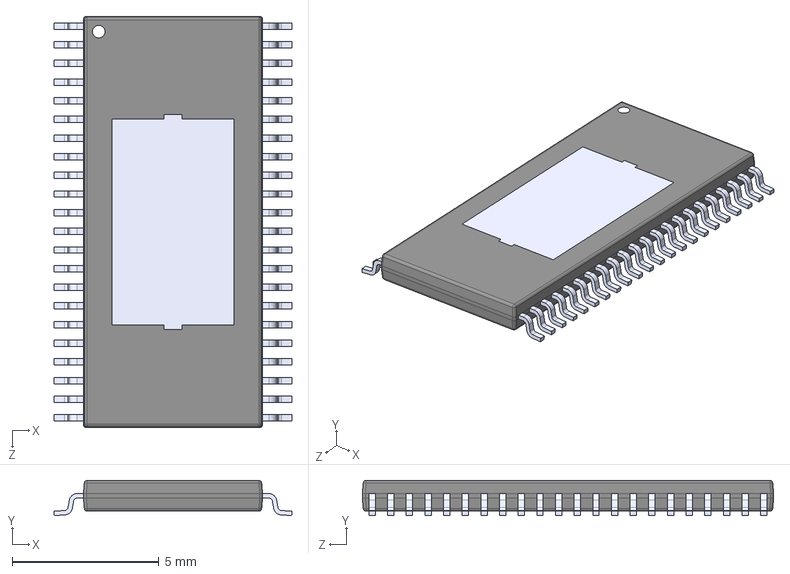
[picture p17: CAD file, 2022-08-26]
TPA3255DDV/TPA3255DDV.step
8.10 x 1.20 x 14.0 mm

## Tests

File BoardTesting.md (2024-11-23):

# Test Results:

## Power supplies

### Power supply LEDs

## Signal input

## Noise output

## Power output

## Fault LED

## Reset button

## BW Adjust Button

## VMon test point

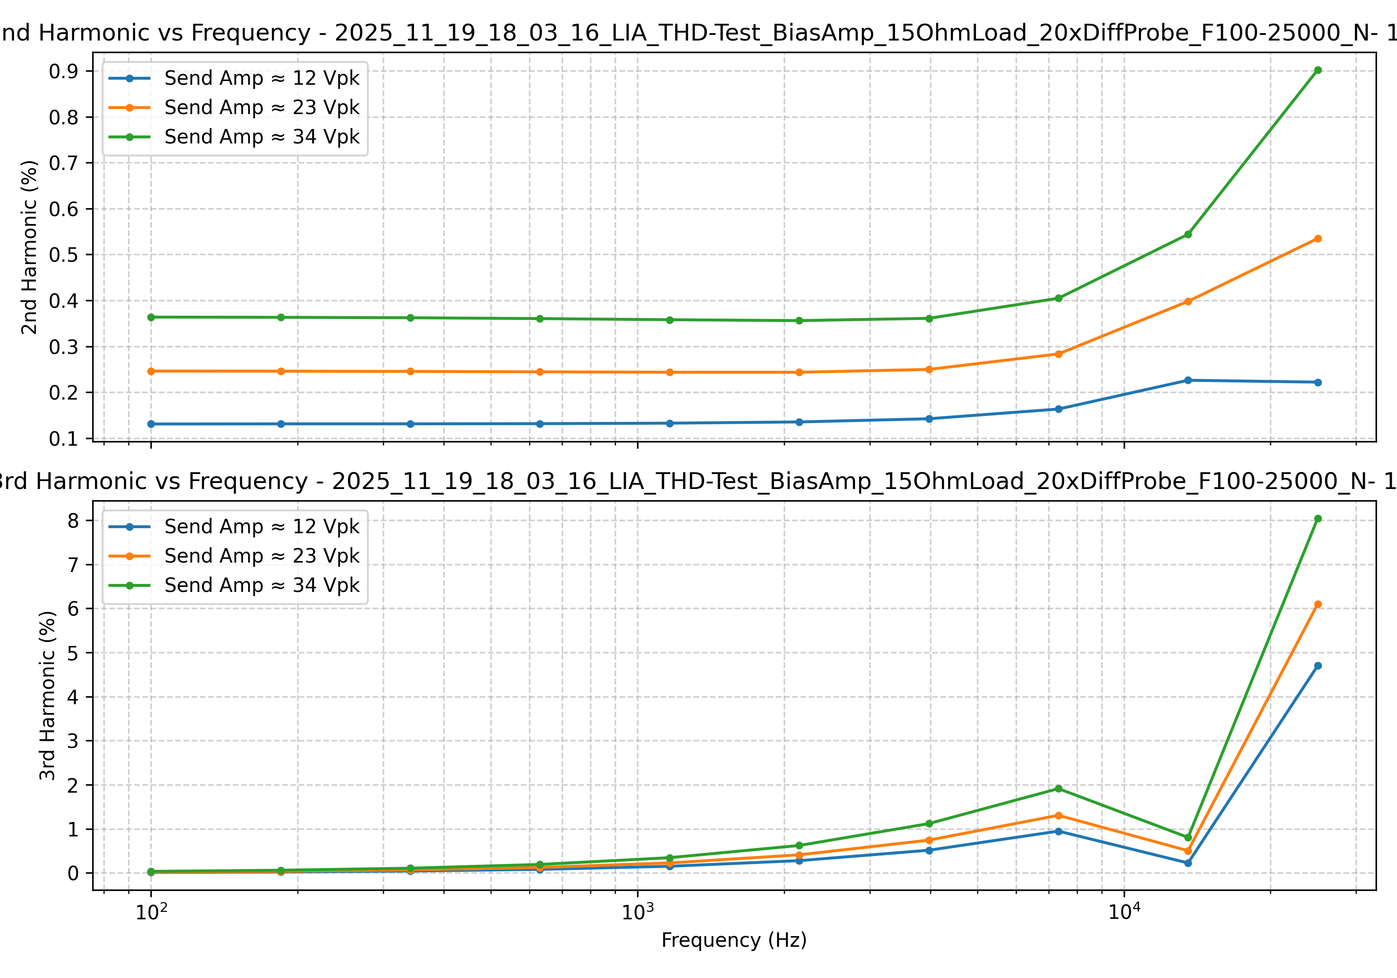
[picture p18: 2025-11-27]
Amplifier Measurements/LIA_THD_vs_freq_2025_11_19_18_03_16_LIA_THD-Test_BiasAmp_15OhmLoad_20xDiffProbe_F100-25000_N-10.png

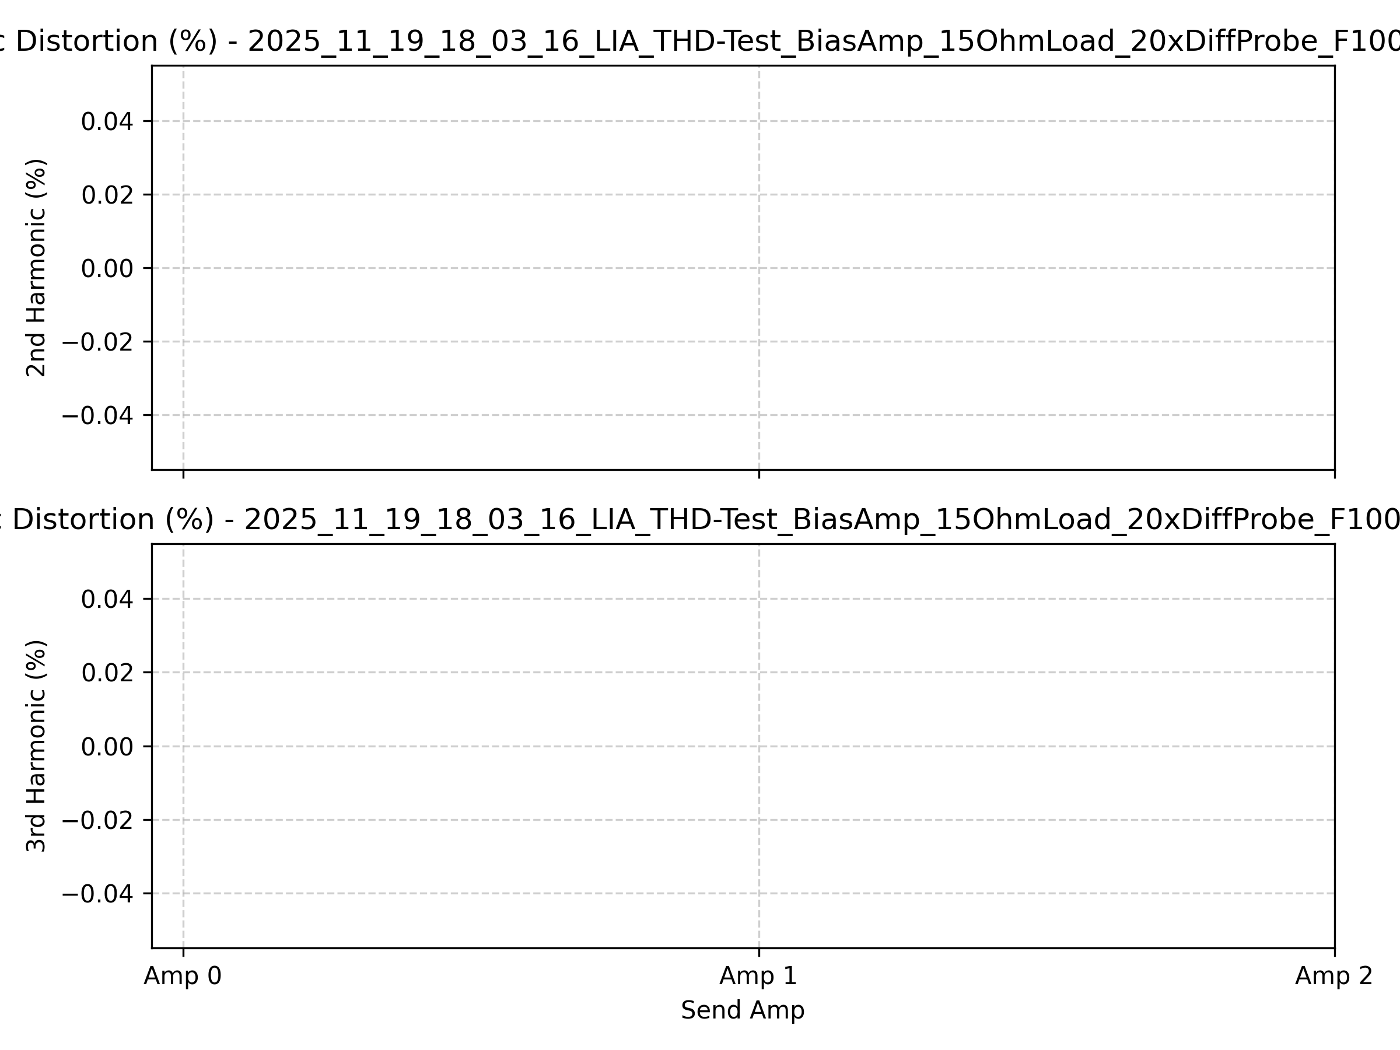
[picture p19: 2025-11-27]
Amplifier Measurements/LIA_THD_2025_11_19_18_03_16_LIA_THD-Test_BiasAmp_15OhmLoad_20xDiffProbe_F100-25000_N-10.png

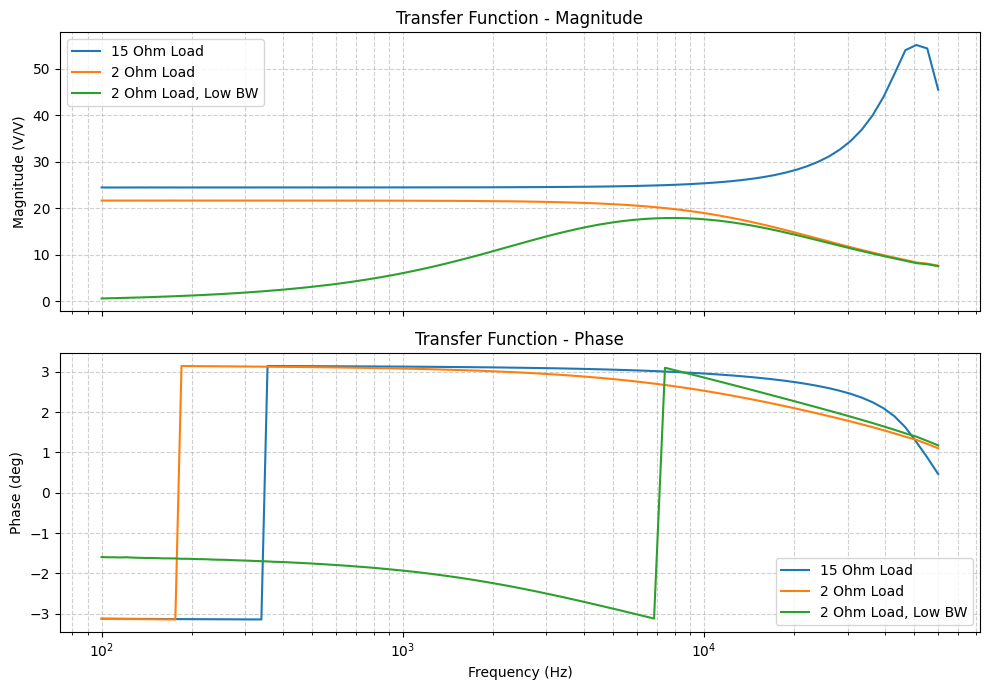
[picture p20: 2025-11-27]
Amplifier Measurements/Gain Plot.png

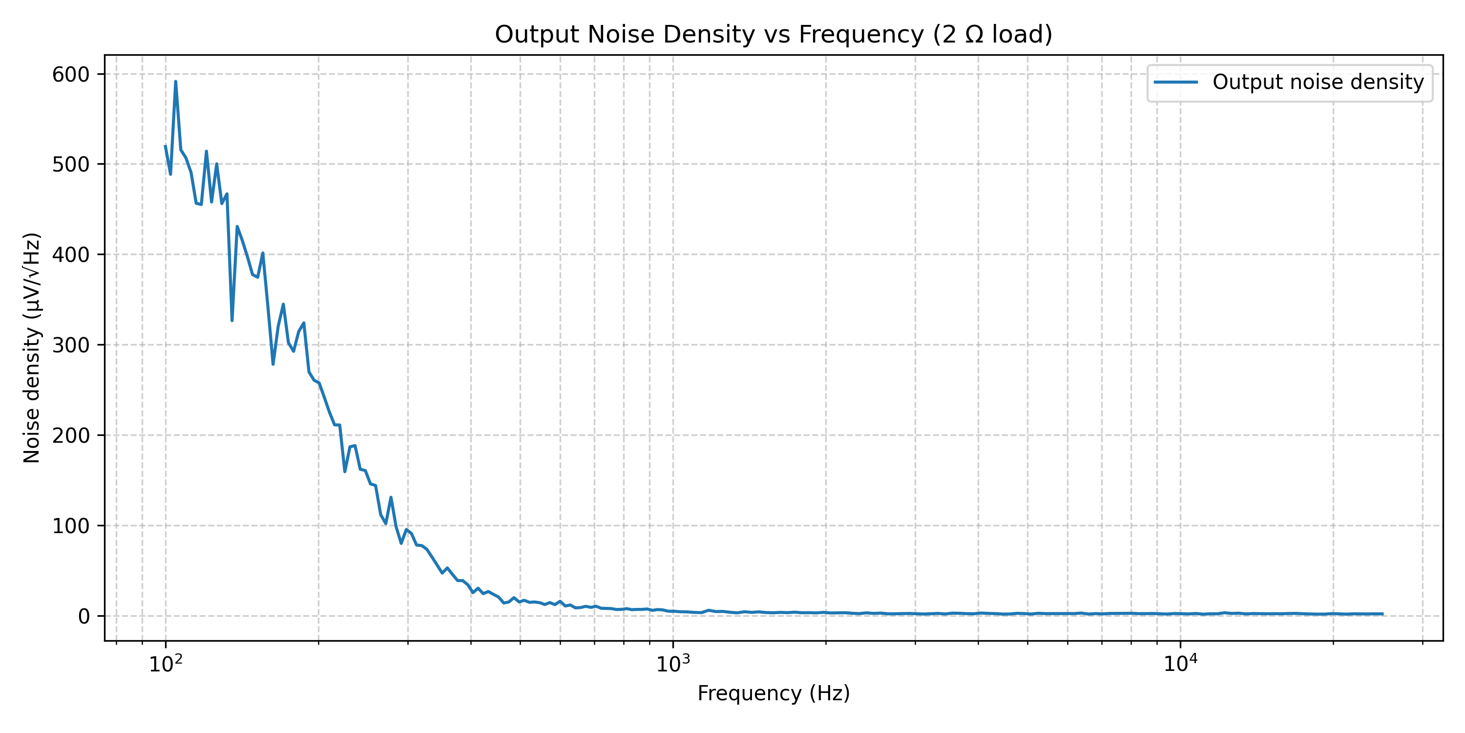
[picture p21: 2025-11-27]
Amplifier Measurements/Output_NoiseDensity.png

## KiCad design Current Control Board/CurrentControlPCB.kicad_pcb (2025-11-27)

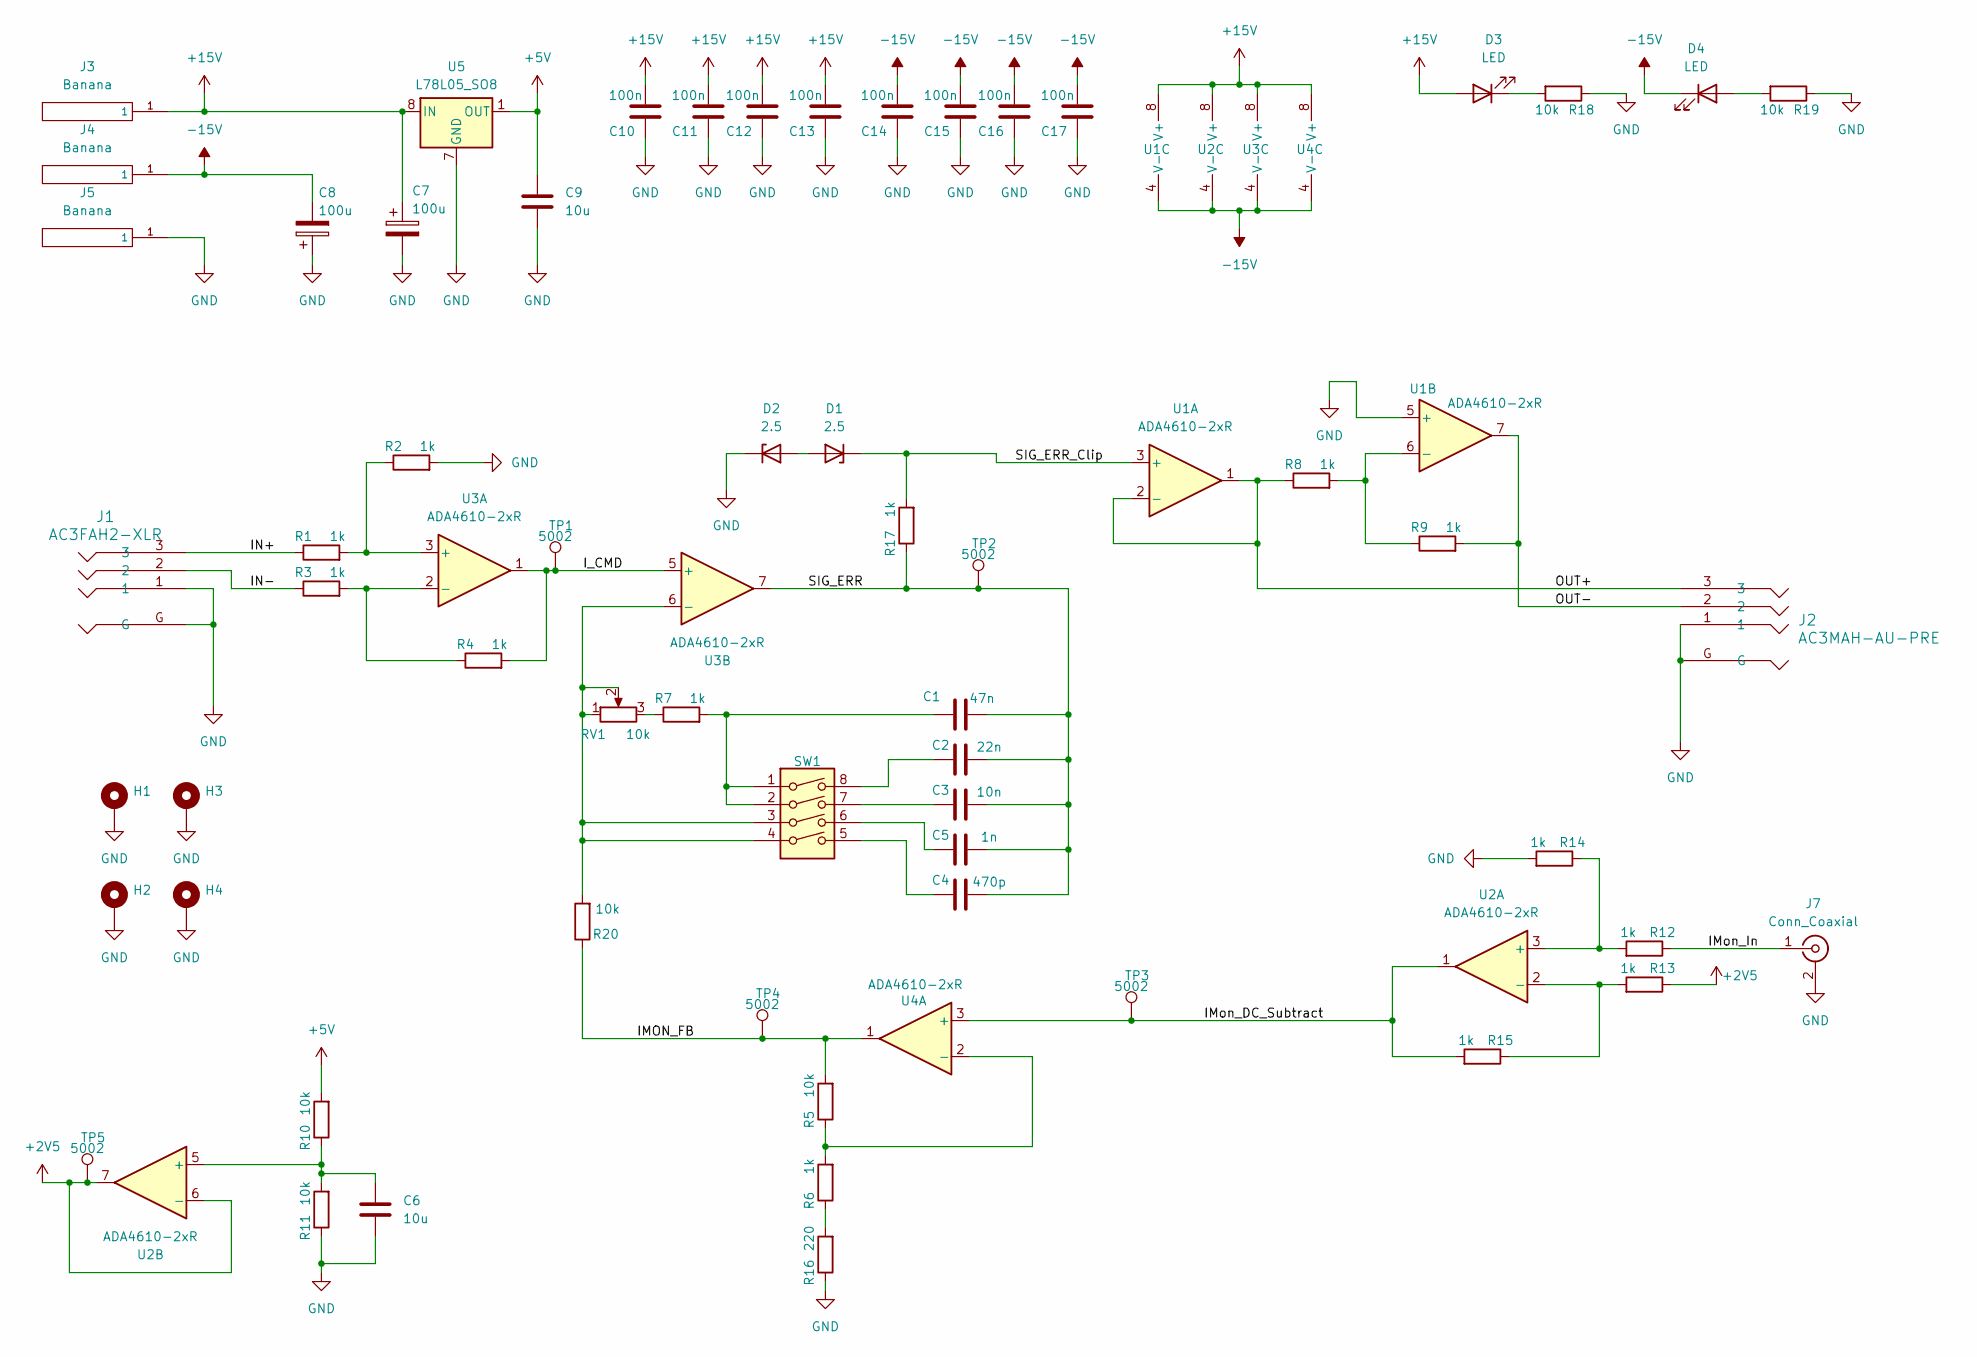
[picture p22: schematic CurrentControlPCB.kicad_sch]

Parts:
C1: 47n; C_0805_2012Metric_Pad1.18x1.45mm_HandSolder
C2: 22n; C_0805_2012Metric_Pad1.18x1.45mm_HandSolder
C3: 10n; C_0805_2012Metric_Pad1.18x1.45mm_HandSolder
C4: 470p; C_0805_2012Metric_Pad1.18x1.45mm_HandSolder
C5: 1n; C_0805_2012Metric_Pad1.18x1.45mm_HandSolder
C6, C9: 10u; C_0805_2012Metric_Pad1.18x1.45mm_HandSolder
C7, C8: 100u; CP_Radial_D6.3mm_P2.50mm
C10, C11, C12, C13, C14, C15, C16, C17: 100n; C_0805_2012Metric_Pad1.18x1.45mm_HandSolder
D1, D2: 2.5; D_SOD-123
D3, D4: LED; LED_0805_2012Metric_Pad1.15x1.40mm_HandSolder
H1, H2, H3, H4: MountingHole_3.2mm_M3_DIN965_Pad
J1: AC3FAH2-XLR; AC3FAH2-F-XLR
J2: AC3MAH-AU-PRE; AC3MAH-AU-PRE_AMP
J3, J4, J5: Banana; Banana-FCR7350L
J7: Conn_Coaxial; 31-5486-1010 BNC Panel RA
R1, R2, R3, R4, R6, R7, R8, R9, R12, R13, R14, R15, R17: 1k; R_0805_2012Metric_Pad1.20x1.40mm_HandSolder
R5, R10, R11, R18, R19, R20: 10k; R_0805_2012Metric_Pad1.20x1.40mm_HandSolder
R16: 220; R_0805_2012Metric_Pad1.20x1.40mm_HandSolder
RV1: 10k; Potentiometer_Bourns_3296W_Vertical
SW1: SW_DIP_x04; SW_DIP_SPSTx04_Slide_9.78x12.34mm_W8.61mm_P2.54mm
TP1, TP2, TP3, TP4, TP5: 5002; TestPoint_Loop_D2.50mm_Drill1.0mm
U1, U2, U3, U4: ADA4610-2xR; SOIC-8_3.9x4.9mm_P1.27mm
U5: L78L05_SO8; SOIC-8_3.9x4.9mm_P1.27mm

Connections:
+2V5: R13.1, TP5.1, U2.6 (-), U2.7
+5V: C9.2, R10.2, U5.1 (OUT)
+15V: C7.1, C10.2, C11.2, C12.2, C13.2, D3.2 (A), J3.1, U1.8 (V+), U2.8 (V+), U3.8 (V+), U4.8 (V+), U5.8 (IN)
-15V: C8.2, C14.2, C15.2, C16.2, C17.2, D4.1 (K), J4.1, U1.4 (V-), U2.4 (V-), U3.4 (V-), U4.4 (V-)
/IMON_FB: R5.2, R20.1, TP4.1, U4.1
/IMon_DC_Subtract: R15.2, TP3.1, U2.1, U4.3 (+)
/IMon_In: J7.1 (In), R12.1
/IN+: J1.3, R1.1
/IN-: J1.2, R3.1
/I_CMD: R4.2, TP1.1, U3.1, U3.5 (+)
/OUT+: J2.3, R8.1, U1.1, U1.2 (-)
/OUT-: J2.2, R9.2, U1.7
/SIG_ERR: C1.2, C2.2, C3.2, C4.2, C5.2, R17.1, TP2.1, U3.7
/SIG_ERR_Clip: D1.1 (K), R17.2, U1.3 (+)
GND: C6.1, C7.2, C8.1, C9.1, C10.1, C11.1, C12.1, C13.1, C14.1, C15.1, C16.1, C17.1, D2.1 (K), H1.1, H2.1, H3.1, H4.1, J1.1, J1.G, J2.1, J2.G, J5.1, J7.2 (Ext), R2.2, R11.1, R14.2, R16.1, R18.1, R19.1, U1.5 (+), U5.2 (GND), U5.3 (GND), U5.6 (GND), U5.7 (GND)
unnamed: C1.1, R7.2, SW1.1, SW1.2
unnamed: C2.1, SW1.8
unnamed: C3.1, SW1.7
unnamed: C4.1, SW1.5
unnamed: C5.1, SW1.6
unnamed: D1.2 (A), D2.2 (A)
unnamed: D3.1 (K), R18.2
unnamed: D4.2 (A), R19.2
unnamed: R7.1, RV1.3
unnamed: R6.1, R16.2
unnamed: R8.2, R9.1, U1.6 (-)
unnamed: R12.2, R14.1, U2.3 (+)
unnamed: R13.2, R15.1, U2.2 (-)
unnamed: C6.2, R10.1, R11.2, U2.5 (+)
unnamed: R1.2, R2.1, U3.3 (+)
unnamed: R3.2, R4.1, U3.2 (-)
unnamed: R20.2, RV1.1, RV1.2, SW1.3, SW1.4, U3.6 (-)
unnamed: R5.1, R6.2, U4.2 (-)

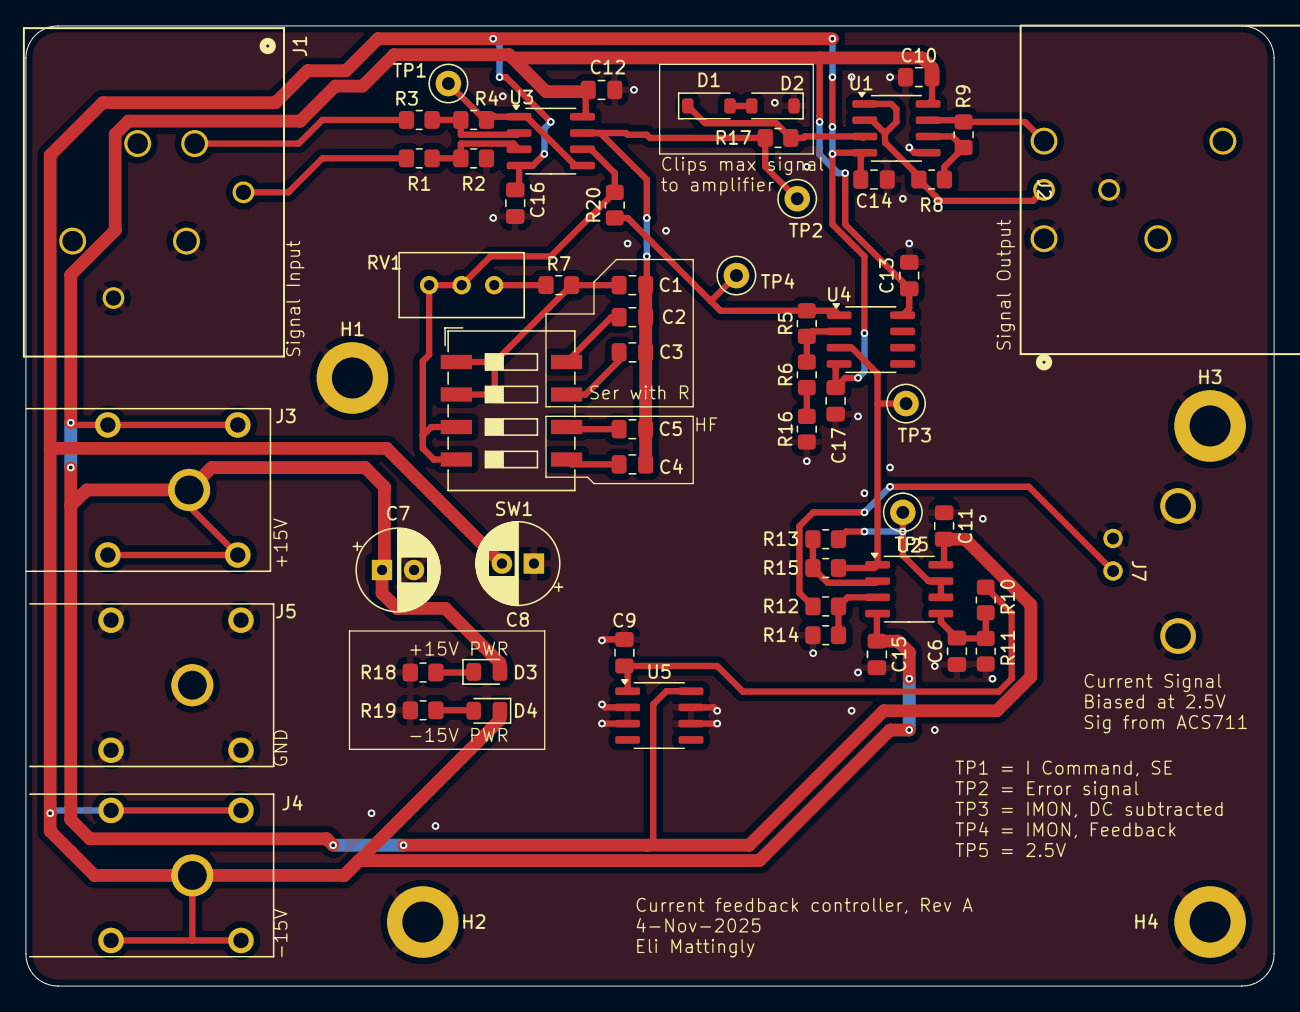
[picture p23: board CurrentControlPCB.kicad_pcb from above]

Board: 2 copper layers, 97.5 x 75.0 mm, 63 parts (0 on the bottom side), 33 nets.

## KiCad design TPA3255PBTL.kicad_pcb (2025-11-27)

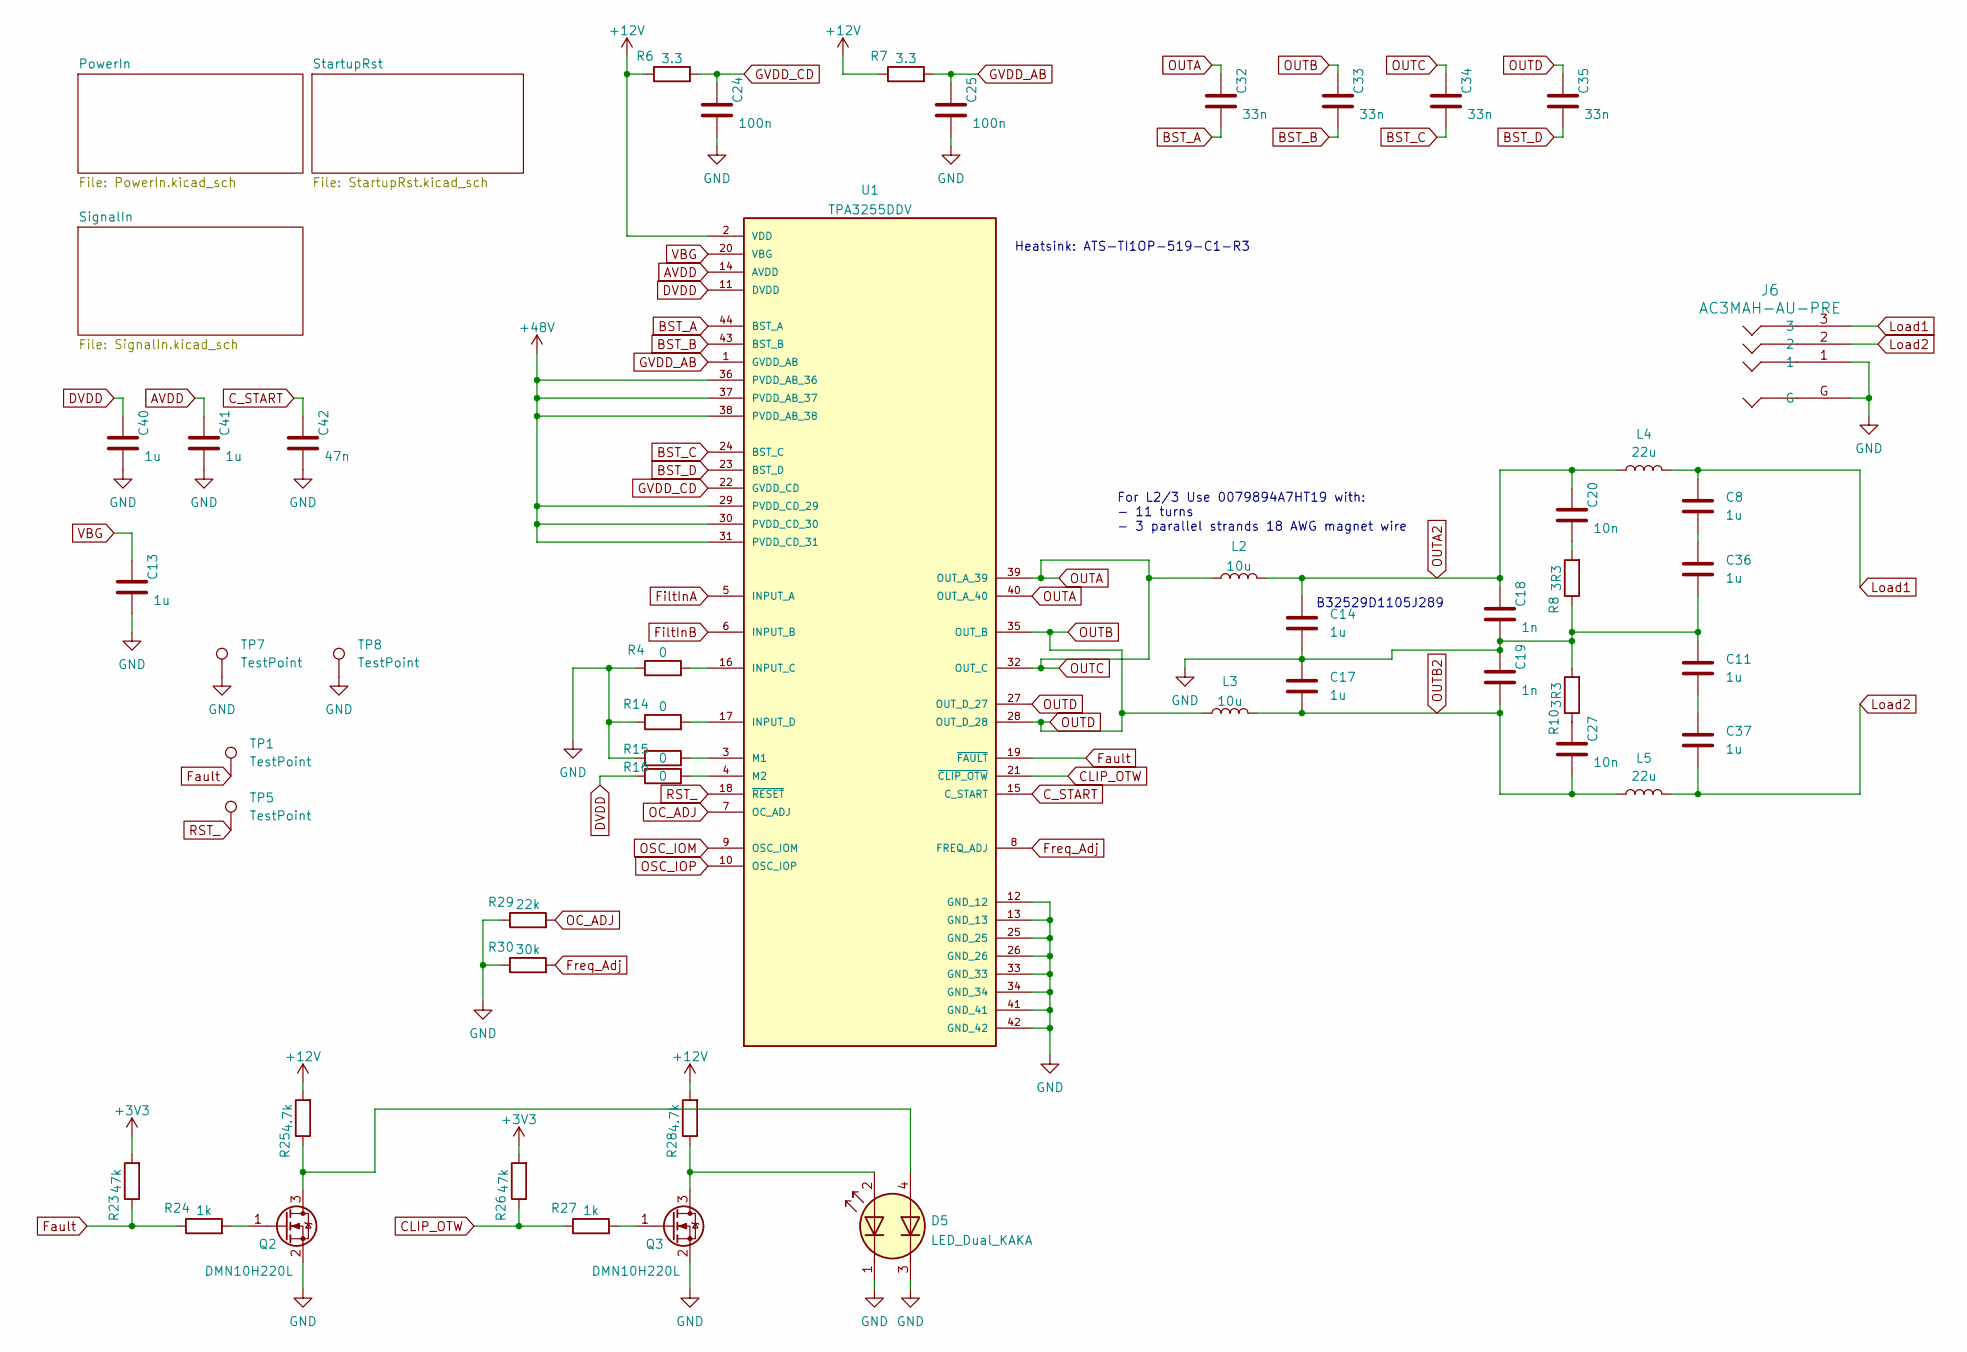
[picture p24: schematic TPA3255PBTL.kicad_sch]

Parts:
C8, C11, C14, C17, C36, C37: 1u; C_Rect_L7.2mm_W7.2mm_P5.00mm_FKS2_FKP2_MKS2_MKP2
C13, C40, C41: 1u; C_0805_2012Metric
C18, C19: 1n; C_0805_2012Metric
C20, C27: 10n; C_0805_2012Metric
C24, C25: 100n; C_0805_2012Metric
C32, C33, C34, C35: 33n; C_0805_2012Metric
C42: 47n; C_0805_2012Metric
D5: LED_Dual_KAKA; IC4_WP934EB_2GD_KNB
J6: AC3MAH-AU-PRE; AC3MAH-AU-PRE_AMP
L2, L3: 10u; L_Toroid_Vertical_L22.4mm_W10.2mm_P7.90mm_Vishay_TJ4
L4, L5: 22u; L_Toroid_Vertical_L22.4mm_W10.2mm_P7.90mm_Vishay_TJ4
Q2, Q3: DMN10H220L; SOT-23
R4, R14, R15, R16: 0; R_0805_2012Metric
R6, R7: 3.3; R_0805_2012Metric
R8, R10: 3R3; R_0805_2012Metric
R23, R26: 47k; R_0805_2012Metric
R24, R27: 1k; R_0805_2012Metric
R25, R28: 4.7k; R_0805_2012Metric
R29: 22k; R_0805_2012Metric
R30: 30k; R_0805_2012Metric
TP1, TP5, TP7, TP8: TestPoint; TestPoint_THTPad_1.0x1.0mm_Drill0.5mm
U1: TPA3255DDV; SOP63P810X120-44N; PARTREV A

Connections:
+3V3: R23.2, R26.2; also elsewhere on the board
+12V: R6.1, R7.1, R25.2, R28.2, U1.2 (VDD); also elsewhere on the board
+48V: U1.29 (PVDD_CD_29), U1.30 (PVDD_CD_30), U1.31 (PVDD_CD_31), U1.36 (PVDD_AB_36), U1.37 (PVDD_AB_37), U1.38 (PVDD_AB_38); also elsewhere on the board
AVDD: C41.1, U1.14 (AVDD)
BST_A: C32.2, U1.44 (BST_A)
BST_B: C33.2, U1.43 (BST_B)
BST_C: C34.2, U1.24 (BST_C)
BST_D: C35.2, U1.23 (BST_D)
CLIP_OTW: R26.1, R27.1, U1.21 (~CLIP_OTW)
C_START: C42.1, U1.15 (C_START)
DVDD: C40.1, R16.1, U1.11 (DVDD)
Fault: R23.1, R24.1, TP1.1, U1.19 (~FAULT)
FiltInA: U1.5 (INPUT_A); also elsewhere on the board
FiltInB: U1.6 (INPUT_B); also elsewhere on the board
Freq_Adj: R30.2, U1.8 (FREQ_ADJ)
GND: C11.1, C13.2, C14.2, C17.1, C18.2, C19.1, C24.2, C25.2, C36.2, C40.2, C41.2, C42.2, D5.1 (A1), D5.3 (A2), J6.1, J6.G, Q2.2 (S), Q3.2 (S), R4.1, R8.1, R10.2, R14.1, R15.1, R29.1, R30.1, TP7.1, TP8.1, U1.12 (GND_12), U1.13 (GND_13), U1.25 (GND_25), U1.26 (GND_26), U1.33 (GND_33), U1.34 (GND_34), U1.41 (GND_41), U1.42 (GND_42); also elsewhere on the board
GVDD_AB: C25.1, R7.2, U1.1 (GVDD_AB)
GVDD_CD: C24.1, R6.2, U1.22 (GVDD_CD)
Load1: C8.1, J6.3, L4.2; also elsewhere on the board
Load2: C37.2, J6.2, L5.2; also elsewhere on the board
unnamed: C11.2, C37.1
unnamed: C20.2, R8.2
unnamed: C27.1, R10.1
unnamed: C8.2, C36.1
unnamed: D5.2 (K1), Q3.3 (D), R28.1
unnamed: D5.4 (K2), Q2.3 (D), R25.1
unnamed: Q2.1 (G), R24.2
unnamed: Q3.1 (G), R27.2
unnamed: R4.2, U1.16 (INPUT_C)
unnamed: R14.2, U1.17 (INPUT_D)
unnamed: R15.2, U1.3 (M1)
unnamed: R16.2, U1.4 (M2)
OC_ADJ: R29.2, U1.7 (OC_ADJ)
OSC_IOM: U1.9 (OSC_IOM)
OSC_IOP: U1.10 (OSC_IOP)
OUTA: C32.1, C34.1, L2.1, U1.32 (OUT_C), U1.39 (OUT_A_39), U1.40 (OUT_A_40)
OUTA2: C14.1, C18.1, C20.1, L2.2, L4.1
OUTB: C33.1, C35.1, L3.1, U1.27 (OUT_D_27), U1.28 (OUT_D_28), U1.35 (OUT_B)
OUTB2: C17.2, C19.2, C27.2, L3.2, L5.1
RST_: TP5.1, U1.18 (~RESET); also elsewhere on the board
VBG: C13.1, U1.20 (VBG)

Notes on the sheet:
B32529D1105J289
For L2/3 Use 0079894A7HT19 with: - 11 turns - 3 parallel strands 18 AWG magnet wire
Heatsink: ATS-TI1OP-519-C1-R3

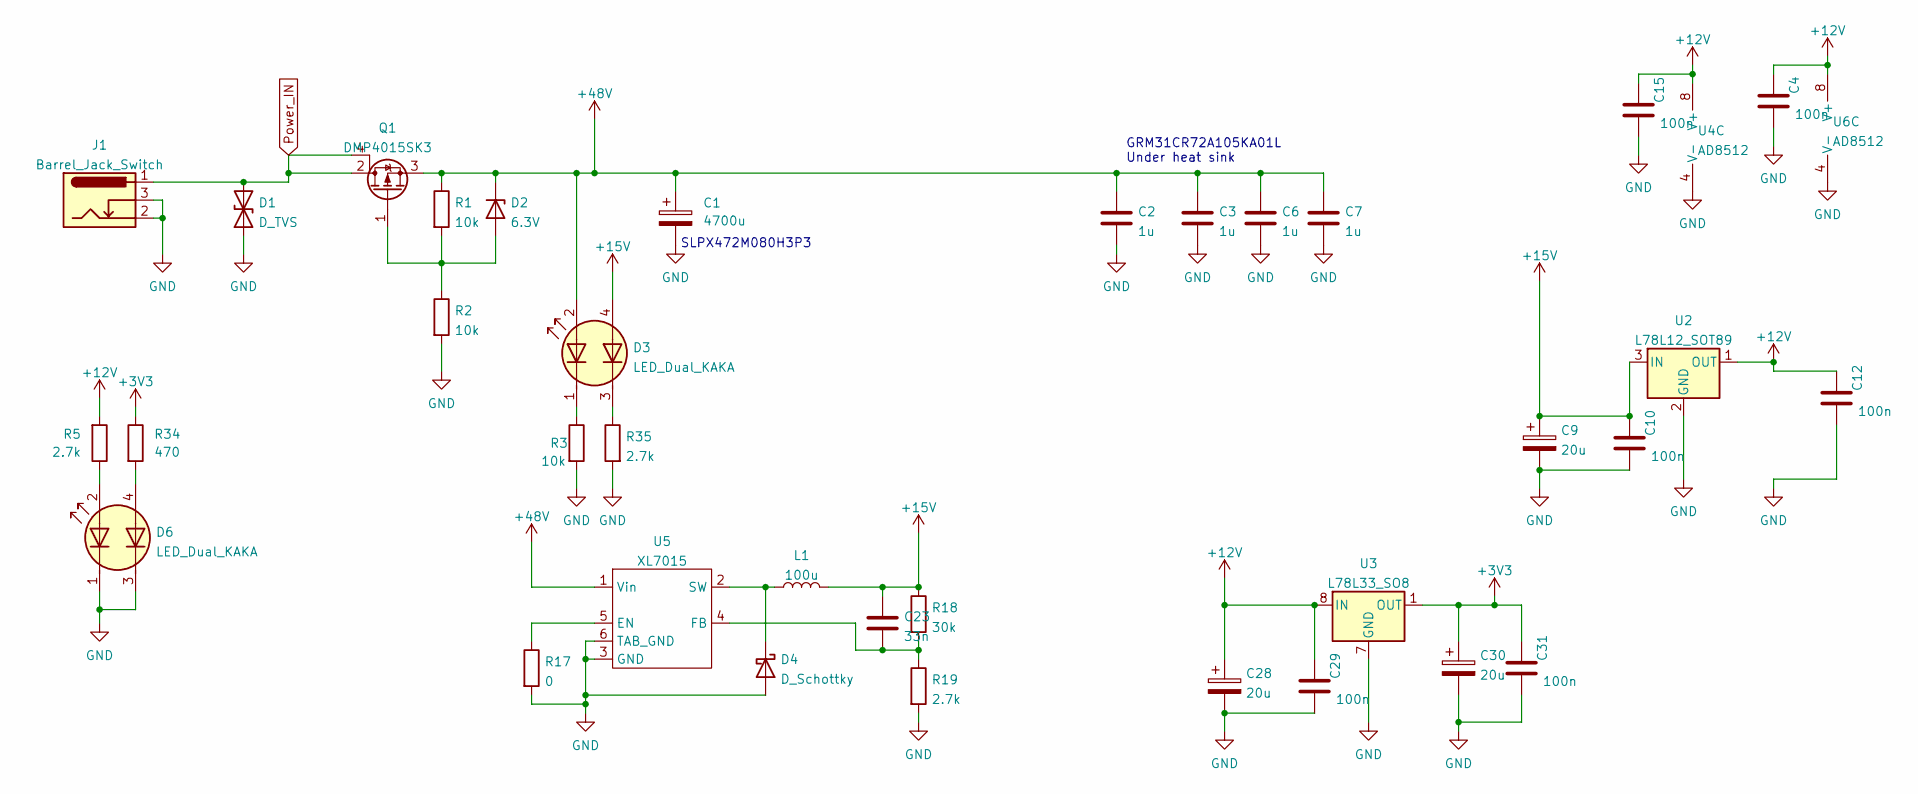
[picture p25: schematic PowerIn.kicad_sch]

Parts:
C1: 4700u; CP_Radial_D35.0mm_P10.00mm_SnapIn
C2, C3, C6, C7: 1u; C_1206_3216Metric
C4, C10, C12, C15, C29, C31: 100n; C_0805_2012Metric
C9, C28, C30: 20u; CP_Radial_D6.3mm_P2.50mm
C23: 33n; C_0805_2012Metric
D1: D_TVS; D_SOD-123
D2: 6.3V; D_SOD-123
D3, D6: LED_Dual_KAKA; IC4_WP934EB_2GD_KNB
D4: D_Schottky; D_SOD-123
J1: Barrel_Jack_Switch; BarrelJack_GCT_DCJ200-10-A_Horizontal
L1: 100u; MWPY8040; LCSC C501759
Q1: DMP4015SK3; TO-252-3_TabPin4
R1, R2, R3: 10k; R_0805_2012Metric
R5, R19, R35: 2.7k; R_0805_2012Metric
R17: 0; R_0805_2012Metric
R18: 30k; R_0805_2012Metric
R34: 470; R_0805_2012Metric
U2: L78L12_SOT89; SOT-89-3
U3: L78L33_SO8; SOIC-8_3.9x4.9mm_P1.27mm
U4, U6: AD8512; SO-8_3.9x4.9mm_P1.27mm
U5: XL7015; XL7015E1

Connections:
+3V3: C30.1, C31.1, R34.1, U3.1 (OUT); also elsewhere on the board
+12V: C4.1, C12.1, C15.1, C28.1, C29.1, R5.2, U2.1 (OUT), U3.8 (IN), U4.8 (V+), U6.8 (V+); also elsewhere on the board
+15V: C9.1, C10.1, C23.1, D3.4 (K2), L1.2, R18.1, U2.3 (IN)
+48V: C1.1, C2.1, C3.1, C6.1, C7.1, D2.1 (K), D3.2 (K1), Q1.3 (S), R1.1, U5.1 (Vin); also elsewhere on the board
GND: C1.2, C2.2, C3.2, C4.2, C6.2, C7.2, C9.2, C10.2, C12.2, C15.2, C28.2, C29.2, C30.2, C31.2, D1.1 (A1), D4.2 (A), D6.1 (A1), D6.3 (A2), J1.2, J1.3, R2.2, R3.2, R17.2, R19.2, R35.2, U2.2 (GND), U3.2 (GND), U3.3 (GND), U3.6 (GND), U3.7 (GND), U4.4 (V-), U5.3 (GND), U5.6 (TAB_GND), U6.4 (V-); also elsewhere on the board
unnamed: D2.2 (A), Q1.1 (G), R1.2, R2.1
unnamed: D3.1 (A1), R3.1
unnamed: D3.3 (A2), R35.1
unnamed: D4.1 (K), L1.1, U5.2 (SW)
unnamed: D6.2 (K1), R5.1
unnamed: D6.4 (K2), R34.2
unnamed: R17.1, U5.5 (EN)
unnamed: C23.2, R18.2, R19.1, U5.4 (FB)
Power_IN: D1.2 (A2), J1.1, Q1.2 (D), Q1.4 (D)

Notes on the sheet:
GRM31CR72A105KA01L Under heat sink
SLPX472M080H3P3

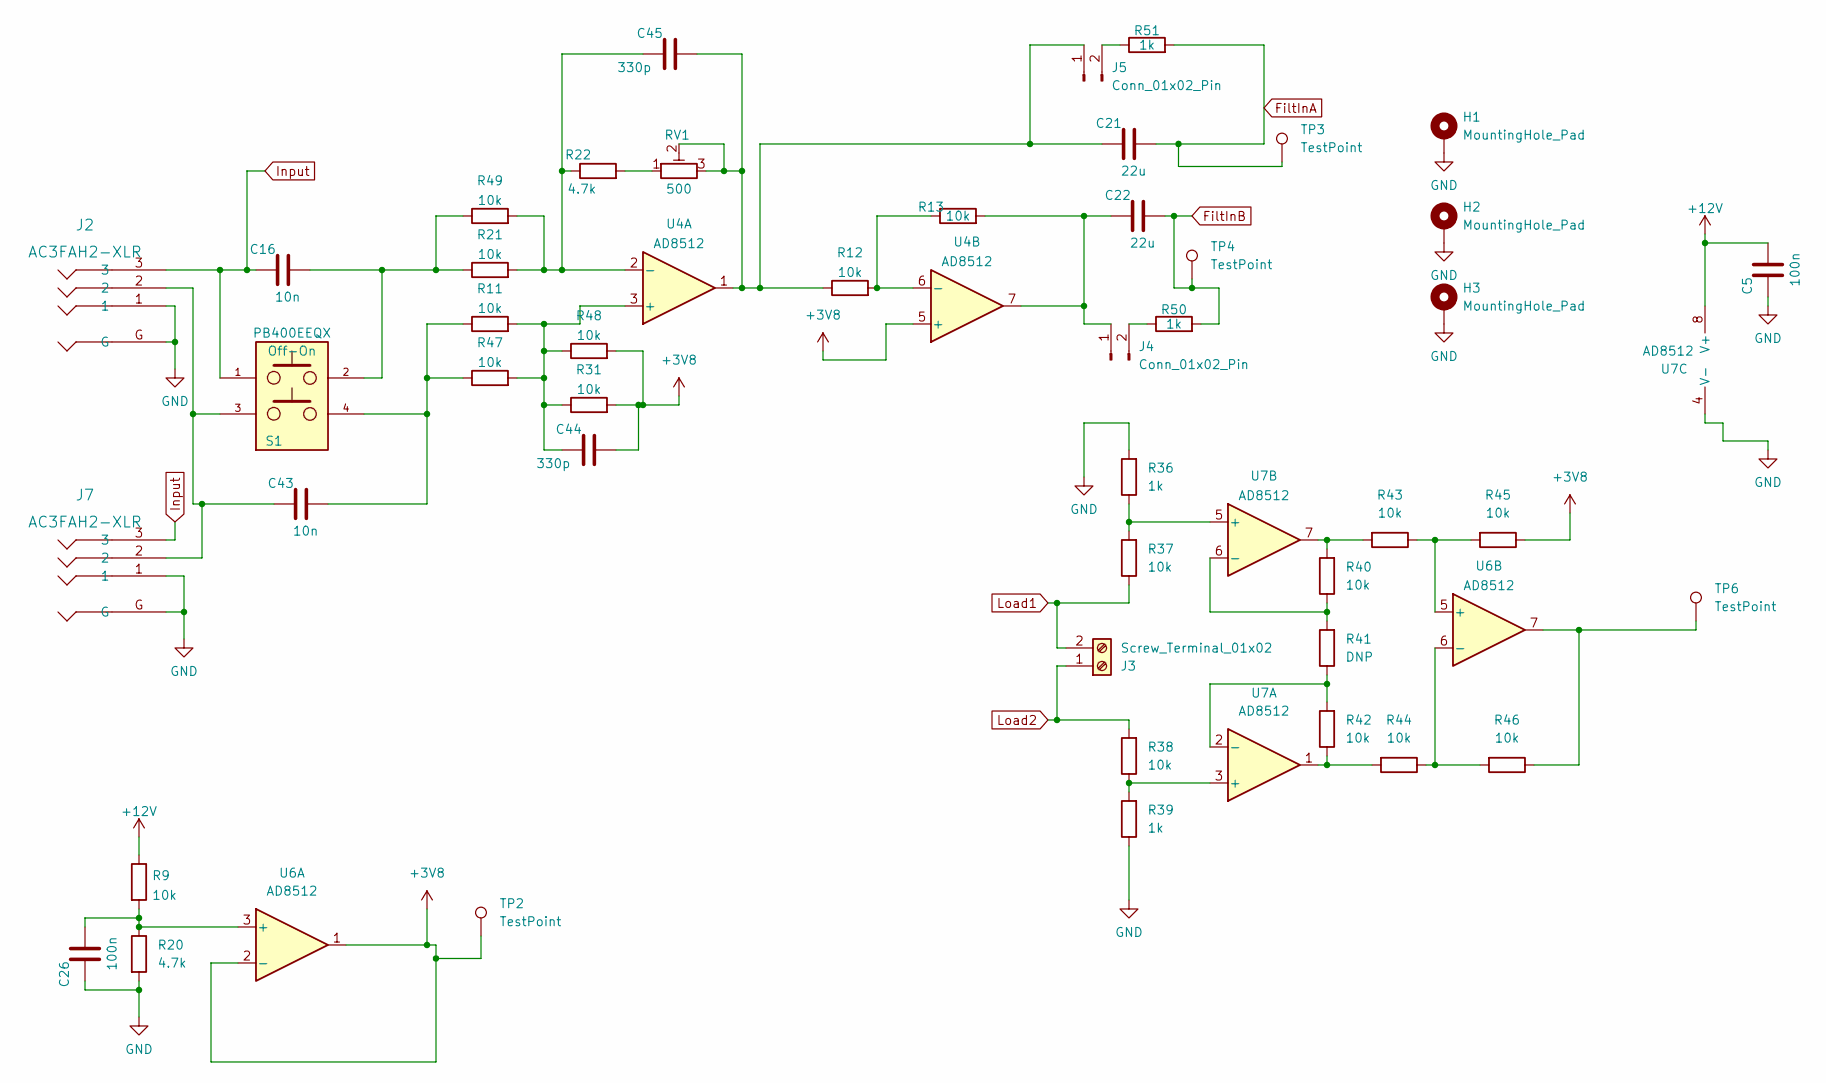
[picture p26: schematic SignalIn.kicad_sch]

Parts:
C5, C26: 100n; C_0805_2012Metric
C16, C43: 10n; C_0805_2012Metric
C21, C22: 22u; C_1206_3216Metric_Pad1.33x1.80mm_HandSolder
C44, C45: 330p; C_0805_2012Metric
H1, H2, H3: MountingHole_Pad; MountingHole_3.2mm_M3_Pad_Via
J2, J7: AC3FAH2-XLR; AC3FAH2-F-XLR
J3: Screw_Terminal_01x02; TerminalBlock_Phoenix_MKDS-1,5-2-5.08_1x02_P5.08mm_Horizont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
J4, J5: Conn_01x02_Pin; PinHeader_1x02_P1.27mm_Vertical
R9, R11, R12, R13, R21, R31, R37, R38, R40, R42, R43, R44, R45, R46, R47, R48, R49: 10k; R_0805_2012Metric
R20, R22: 4.7k; R_0805_2012Metric
R36, R39, R50, R51: 1k; R_0805_2012Metric
R41: DNP; R_0805_2012Metric
RV1: 500; Potentiometer_Bourns_3296W_Vertical
S1: PB400EEQX; SW_PB400EEQX; PARTREV NA
TP2, TP3, TP4, TP6: TestPoint; TestPoint_THTPad_1.0x1.0mm_Drill0.5mm
U4, U6, U7: AD8512; SO-8_3.9x4.9mm_P1.27mm

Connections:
+3V8: C44.2, R31.2, R45.1, R48.2, TP2.1, U4.5 (+), U6.1, U6.2 (-)
+12V: C5.2, R9.1, U7.8 (V+); also elsewhere on the board
FiltInA: C21.2, R51.2, TP3.1; also elsewhere on the board
FiltInB: C22.2, R50.2, TP4.1; also elsewhere on the board
GND: C5.1, C26.1, H1.1, H2.1, H3.1, J2.1, J2.G, J7.1, J7.G, R20.2, R36.2, R39.1, U7.4 (V-); also elsewhere on the board
Input: C16.1, J2.3, J7.3, S1.1
Load1: J3.2, R37.1; also elsewhere on the board
Load2: J3.1, R38.2; also elsewhere on the board
unnamed: C16.2, R21.1, R49.1, S1.2
unnamed: C43.1, J2.2, J7.2, S1.3
unnamed: C43.2, R11.1, R47.1, S1.4
unnamed: C22.1, J4.1, R13.2, U4.7
unnamed: J4.2, R50.1
unnamed: C21.1, C45.2, J5.1, R12.1, RV1.2, RV1.3, U4.1
unnamed: J5.2, R51.1
unnamed: R22.2, RV1.1
unnamed: R40.2, R43.2, U7.7
unnamed: R42.1, R44.2, U7.1
unnamed: R46.1, TP6.1, U6.7
unnamed: C44.1, R11.2, R31.1, R47.2, R48.1, U4.3 (+)
unnamed: C45.1, R21.2, R22.1, R49.2, U4.2 (-)
unnamed: R12.2, R13.1, U4.6 (-)
unnamed: C26.2, R9.2, R20.1, U6.3 (+)
unnamed: R43.1, R45.2, U6.5 (+)
unnamed: R44.1, R46.2, U6.6 (-)
unnamed: R38.1, R39.2, U7.3 (+)
unnamed: R41.1, R42.2, U7.2 (-)
unnamed: R36.1, R37.2, U7.5 (+)
unnamed: R40.1, R41.2, U7.6 (-)

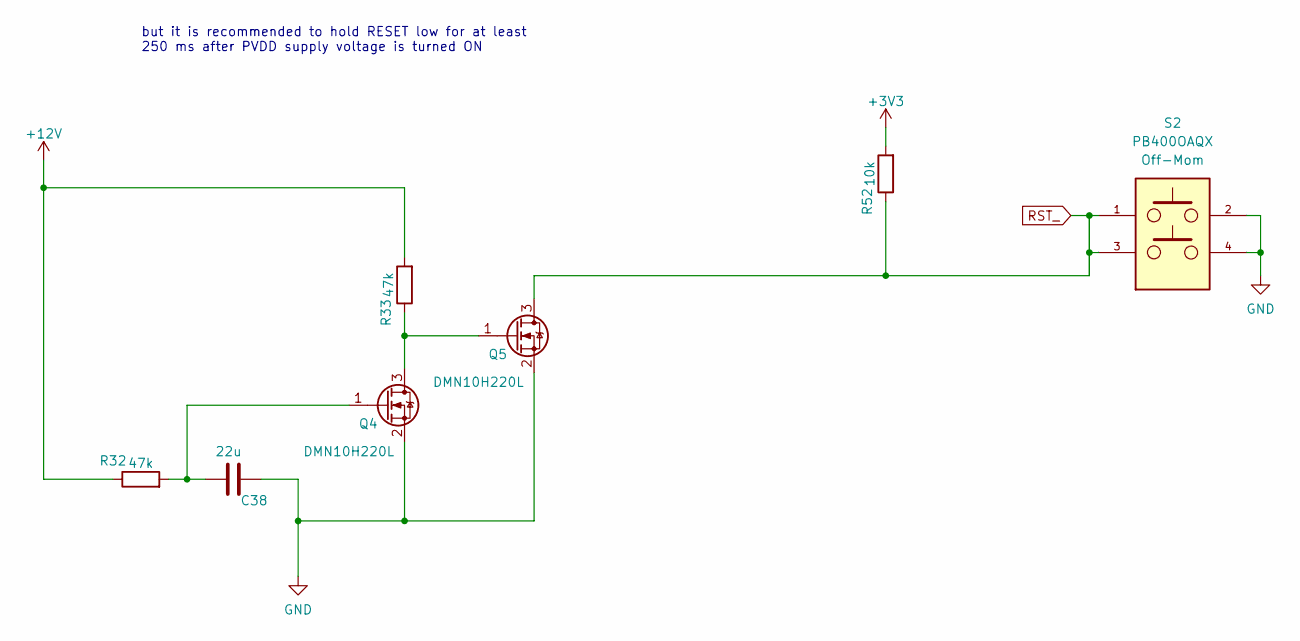
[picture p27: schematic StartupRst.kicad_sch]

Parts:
C38: 22u; C_1206_3216Metric_Pad1.33x1.80mm_HandSolder
Q4, Q5: DMN10H220L; SOT-23
R32, R33: 47k; R_0805_2012Metric
R52: 10k; R_0805_2012Metric
S2: PB400OAQX; SW_PB400EEQX; PARTREV NA

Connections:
+3V3: R52.2; also elsewhere on the board
+12V: R32.1, R33.2; also elsewhere on the board
GND: C38.1, Q4.2 (S), Q5.2 (S), S2.2, S2.4; also elsewhere on the board
unnamed: Q4.3 (D), Q5.1 (G), R33.1
unnamed: C38.2, Q4.1 (G), R32.2
RST_: Q5.3 (D), R52.1, S2.1, S2.3; also elsewhere on the board

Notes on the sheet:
but it is recommended to hold RESET low for at least 250 ms after PVDD supply voltage is turned ON

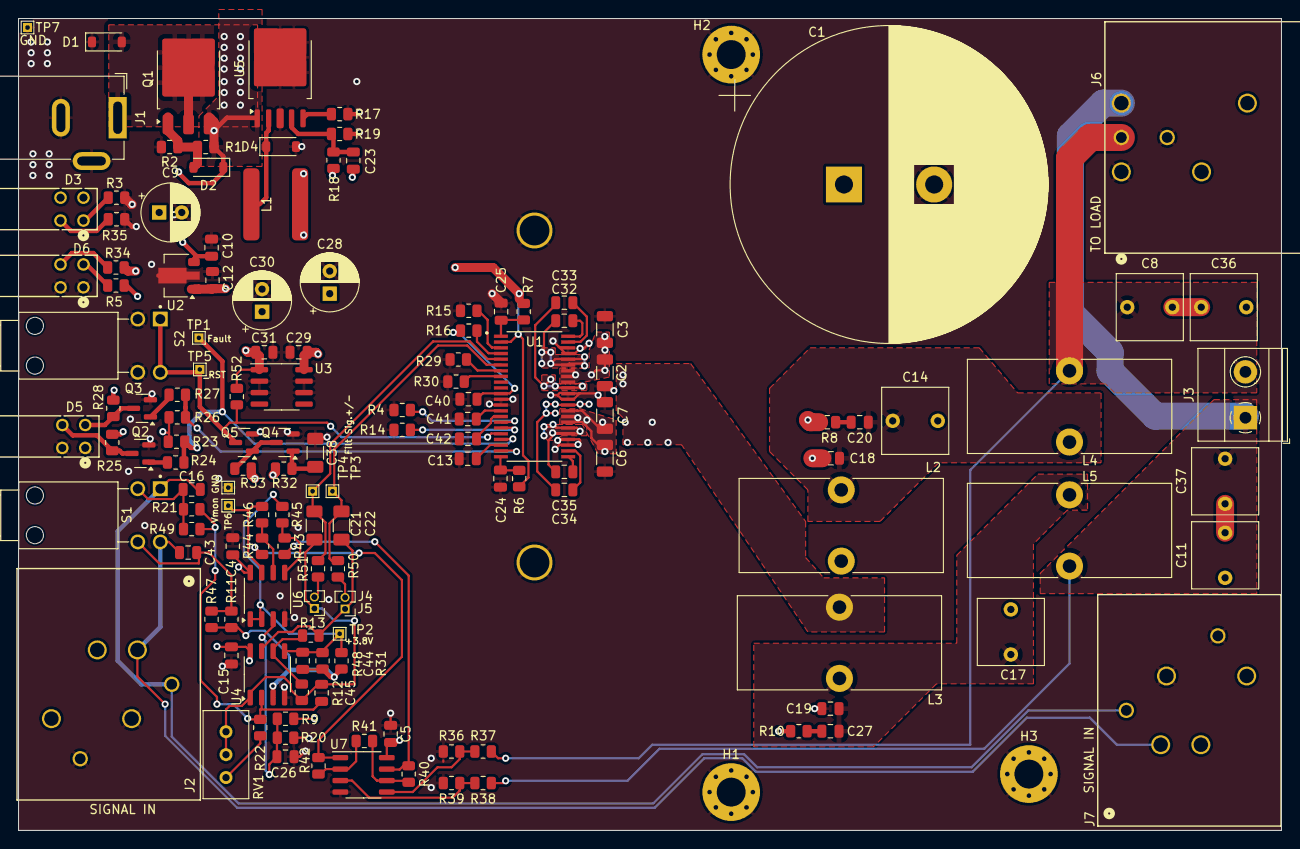
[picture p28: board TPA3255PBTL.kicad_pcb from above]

Board: 4 copper layers, 140.0 x 90.0 mm, 140 parts (0 on the bottom side), 74 nets.

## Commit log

2022-08-26 First Draft
    [PowerIn.kicad_sch, SignalIn.kicad_sch, TPA3255DDV.step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]
2022-08-26 Update Layout
    [PowerIn.kicad_sch, SignalIn.kicad_sch, TPA3255PBTL.kicad_pcb]
2023-01-05 pre fab-no heatsink
    [TPA3255PBTL-B_Cu.gbr, TPA3255PBTL-B_Mask.gbr, TPA3255PBTL-B_Paste.gbr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]
2024-09-07 Update, Post mfg
    [PowerIn.kicad_sch, SignalIn.kicad_sch, StartupRst.kicad_sch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]
2024-11-23 Pre mfg, Rev B
    [PowerIn.kicad_sch, SignalIn.kicad_sch, TPA3255PBTL.kicad_pcb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]
2024-11-23 minor changes
    [StartupRst.kicad_sch, TPA3255PBTL.kicad_sch]
2025-11-27 Add testing/ update README/ Current control
    [CurrentControlPCB.kicad_pcb, CurrentControlPCB.kicad_sch, PowerIn.kicad_sch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]
